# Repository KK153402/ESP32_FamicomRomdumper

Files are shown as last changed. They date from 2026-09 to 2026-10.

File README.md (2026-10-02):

# Famicom ROM Dumper

ESP32と汎用ロジックICで作る、ファミコン（Family Computer）カセットのROM吸い出し機です。
吸い出したデータはiNES形式（`.nes`）で保存され、エミュレータ（Mesen等）でそのまま起動できます。

A Famicom cartridge ROM dumper built with an ESP32 and standard 74-series logic.
Dumps are saved in iNES format (`.nes`) and boot directly in emulators such as Mesen.

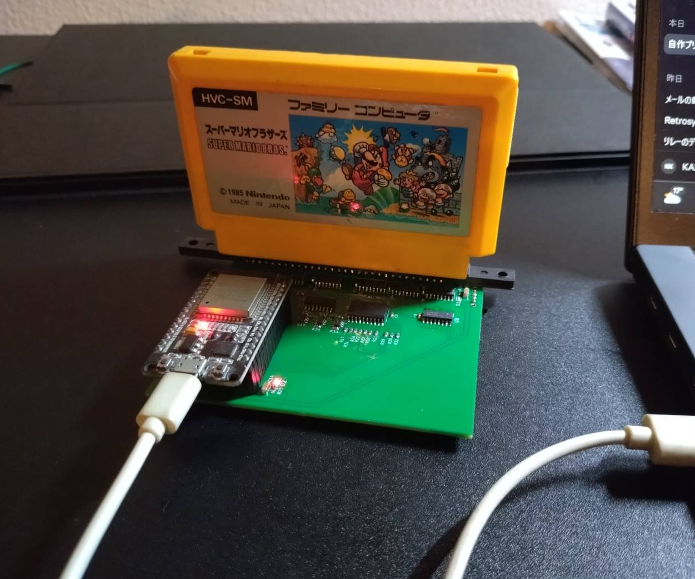
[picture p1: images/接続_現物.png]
基板の外観

<!-- 基板写真 / board photo -->
<!-- ![board](docs/images/board.jpg) -->

---

## 特徴 / Features

- **ESP32 + シフトレジスタ構成**：74HCT595 ×6 / 74HCT165 ×2 でカセットバス54本をGPIO 16本に圧縮
- **5V系ロジックを直接駆動**：シフトレジスタを5Vで動かし、TTLしきい値（HCT/AHCT）で3.3V信号を受ける。大量のレベル変換ICが不要
- **カセット保護**：カセット電源（`VCC_CART`）の独立遮断と、バス全体のHi-Z化（`BUS_EN_N`）
- **ダンプの信頼性**：2回読み出して一致を確認し、CRC32で転送エラーも検出
- **自動判定**：PRG容量（16 KB / 32 KB）とミラーリング（垂直 / 水平）

- **ESP32 + shift registers**: 54 cartridge bus signals driven from 16 GPIOs using 6× 74HCT595 and 2× 74HCT165
- **Direct 5 V logic drive**: shift registers run at 5 V with TTL input thresholds (HCT/AHCT), accepting 3.3 V signals without bulk level shifters
- **Cartridge protection**: switchable cartridge power rail (`VCC_CART`) and bus tri-state control (`BUS_EN_N`)
- **Verified dumps**: every cartridge is read twice and compared; CRC32 checks the serial transfer
- **Auto detection**: PRG size (16 KB / 32 KB) and nametable mirroring (vertical / horizontal)

## 対応カセット / Supported Cartridges

| 状態 | マッパー | 例 |
|---|---|---|
| ✅ 対応 | Mapper 0（NROM-128 / NROM-256） | スーパーマリオブラザーズ、ドンキーコング、バルーンファイト 等 |
| 🚧 未対応 | バンク切替のあるマッパー（UNROM、MMC1、MMC3 など） | 今後対応予定 |

| Status | Mapper | Examples |
|---|---|---|
| ✅ Supported | Mapper 0 (NROM-128 / NROM-256) | Super Mario Bros., Donkey Kong, Balloon Fight, etc. |
| 🚧 Not yet | Bank-switching mappers (UNROM, MMC1, MMC3, ...) | Planned |

60ピンのファミコン用カセット専用です。72ピンの海外版NESカセットは物理的に挿さりません。
For 60-pin Famicom cartridges only. 72-pin NES cartridges do not fit.

## 動作確認済み / Tested

| タイトル | 構成 | 結果 |
|---|---|---|
| スーパーマリオブラザーズ | NROM-256（PRG 32 KB + CHR 8 KB）、垂直ミラー | ✅ Mesenで起動・プレイ確認 |

## リポジトリ構成 / Repository Layout

```
famicom-rom-dumper/
├── README.md
├── LICENSE
├── hardware/           Kicadの回路図,ガーバーデータ
│   └── ERRATA.md       rev1の既知の問題 / Known issues in rev1
├── firmware/           ESP32ファーム（PlatformIO） / ESP32 firmware
├── tools/              PC側ダンプスクリプト / Host-side dump script
└── docs/
    ├── hardware.md     部品表・全接続・電源設計 / BOM, netlist, power design
    ├── bringup.md      組み立て後〜Mesen起動までの手順 / Bring-up to first boot
    ├── protocol.md     シリアルコマンド仕様 / Serial protocol
    └── design-notes.md 設計判断と技術解説 / Design rationale and technical notes
```

## クイックスタート / Quick Start

詳細は [docs/bringup.md](docs/bringup.md) を参照してください。
See [docs/bringup.md](docs/bringup.md) for the full procedure.

1. `firmware/` をPlatformIOでESP32に書き込む / Flash `firmware/` to the ESP32 with PlatformIO
2. カセットを挿してカセット電源スイッチ（SW1）をON / Insert a cartridge and turn SW1 (cartridge power) on
3. PCでダンプ / Dump from the PC:

```
pip install pyserial
python tools/dump_nes.py COM5 game.nes
```

4. SW1をOFFにしてからカセットを抜く / Turn SW1 off before removing the cartridge

```
BUS_EN_N = 0 (enabled)
pass 1: PRG 32KB  CHR 8KB  mirror=V  CRC32=D445F698  (11.5s)
pass 2: CRC32=D445F698
BUS_EN_N = 1 (Hi-Z)
OK: game.nes (40976 bytes)  PRG+CHR CRC32=D445F698
```

## ハードウェア概要 / Hardware Overview

| 部品 / Part | 型番 / Part number | 数 / Qty | 役割 / Role |
|---|---|---|---|
| MCU | ESP32-WROOM-32E DevKit（30ピン） | 1 | 制御・USBシリアル / Control, USB serial<br>[購入先 / Source (AliExpress)](https://ja.aliexpress.com/item/1005008771142129.html) |
| シフトレジスタ（出力） | SN74AHCT595D | 6 | アドレス29本 + データ書き込み16本 / Address and data out |
| シフトレジスタ（入力） | CD74HCT165M | 2 | データ読み出し16本 / Data in |
| バッファ | SN74AHCT244 | 1 | 制御線6本 3.3 V → 5 V / Control lines |
| レベル変換 | SN74LVC1T45 | 3 | 5 V → 3.3 V（MISO、CIRAM 2本） |
| コネクタ | ファミコン60ピン 2.54 mmピッチ | 1 | カセットスロット / Cartridge slot<br>[購入先 / Source (AliExpress)](https://ja.aliexpress.com/item/1005006124592648.html) |

全部品表と接続は [docs/hardware.md](docs/hardware.md) にあります。
The full BOM and netlist are in [docs/hardware.md](docs/hardware.md).

## 注意 / Legal Notice

- **吸い出したROMイメージを配布しないでください。** このツールは、自分が所有するカセットのバックアップや研究目的の私的使用を想定しています。このリポジトリにROMイメージは含まれていません
- **Do not distribute ROM images.** This tool is intended for personal backup and research using cartridges you own. No ROM images are included in this repository.

- カセットの抜き差しは必ずカセット電源（SW1）をOFFにしてから行ってください。通電中の抜き差しはカセットと基板を破損するおそれがあります
- Always turn off cartridge power (SW1) before inserting or removing a cartridge. Hot-swapping can damage both the cartridge and the board.

## 参考資料 / References

- [NESdev Wiki](https://www.nesdev.org/wiki/) — Cartridge connector, iNES format, mapper documentation
- [MesenCE](https://github.com/nesdev-org/MesenCE) — エミュレータ / emulator used for verification

## ライセンス / License

MIT License. ハードウェア（KiCadデータ）・ファームウェア・ツールのすべてに適用します。
MIT License, applied to the hardware design files, firmware, and tools.

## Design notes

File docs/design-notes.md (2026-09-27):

# 設計ノート / Design Notes

このROMダンパーの設計判断の理由と、技術的な背景をまとめた文書です。部品表と接続は [hardware.md](hardware.md)、手順は [bringup.md](bringup.md) を参照してください。

---

## 1. 全体方針

### 1.1 なぜFPGAではなくESP32なのか

ファミコンのカセットに載っているマスクROMは**完全スタティック**です。アドレスを与えて出力を有効にすれば、何秒待っても同じデータを出し続けます。ファミコン本体はCPUサイクル559 ns、PPU読み出しの窓は約372 nsで動いていますが、これは本体側の都合であって、ROMを読むだけならクロックに合わせる必要はありません。

したがって、ダンパーには速度要件がありません。1 kHzで読んでも正しく読めます。この性質を使うと、以下の設計が可能になります。

- 54本のバス信号をシフトレジスタで圧縮し、MCUのGPIO数の制約を回避する
- 汎用MCU（ESP32）とUSBシリアルだけでPCへ転送する

リアルタイムでカセットを駆動する必要がある場合（カセットを挿してそのままゲームを動かす機械）は、PPUの372 nsの窓に間に合わせるためFPGAが必要になります。このダンパーは、その前段階として「カセットのバスを正しく扱えること」を確認する位置づけでもあります。

### 1.2 カセットバスの概要

60ピンのファミコンカセットは、2つの独立したバスを持っています。

| バス | 信号 | 本数 | 内容 |
|---|---|---|---|
| CPUバス | A0〜A14、D0〜D7、M2、/ROMSEL、R/W、/IRQ | 27 | PRG-ROM（プログラム）へのアクセス |
| PPUバス | PA0〜PA13、PD0〜PD7、/RD、/WR、/A13、CIRAM A10、CIRAM /CE | 27 | CHR-ROM（画像データ）へのアクセス、画面用RAMの制御 |

ポイントは以下の3つです。

- **CPUバスにA15は出ていません。** 代わりに `/ROMSEL` = NOT(A15 AND M2) が出ています。`$8000`〜`$FFFF` を読むには、A0〜A14を出してM2 = H、/ROMSEL = L にします
- **CIRAM A10 はカセットからの出力です。** 本体の画面用RAM（2 KB）のアドレスA10をカセットが決めることで、ミラーリング（画面の繋がり方）をカセット側が選べる仕組みです
- ピン間隔は **2.54 mm（0.1インチ）** です。海外版NES（72ピン）の2.50 mmとは異なり、汎用のカードエッジコネクタと同じピッチです

---

## 2. ピン数の圧縮

### 2.1 構成

| 用途 | 本数 | 方式 | ESP32側のピン数 |
|---|---|---|---|
| アドレス（CPU 15 + PPU 14） | 29 | 74AHCT595 × 4 のデイジーチェーン | 共通 |
| データ書き込み（CPU 8 + PPU 8） | 16 | 74AHCT595 × 2 のデイジーチェーン | 共通 |
| データ読み出し（CPU 8 + PPU 8） | 16 | 74HCT165 × 2 のデイジーチェーン | 共通 |
| シフトレジスタの共通線 | — | SCK、MOSI、MISO、RCLK × 2、/OE × 2、/PL | 8 |
| 制御線 | 6 | 74AHCT244 経由で直接 | 6 |
| CIRAM | 2 | 74LVC1T45 経由で直接 | 2 |
| **合計** | **54 + 保護** | | **16** |

アドレス系とデータ系の595は、SCK（シフトクロック）とMOSI（シリアルデータ）を共有しています。出力を更新するタイミング（RCLK）だけを分けているので、片方に送ったデータがもう片方の出力に現れることはありません。

### 2.2 デイジーチェーンのバイト順

595はチェーンの先頭から順にデータが押し出されるため、**最初に送ったバイトがチェーンの末尾のICに到着します**。MSBファーストで送ると、bit7がQH、bit0がQAに対応します。

アドレス系のチェーンは MOSI → U1 → U2 → U3 → U4 なので、送る順番は逆になります。

| 送信順 | 到着するIC | 内容 |
|---|---|---|
| 1バイト目 | U4 | `{00, PA13..PA8}` |
| 2バイト目 | U3 | `{PA7..PA0}` |
| 3バイト目 | U2 | `{0, A14..A8}` |
| 4バイト目 | U1 | `{A7..A0}` |

165は逆方向で、U8 → U7 → MISO の順にチェーンされているので、最初に受け取るバイトがU7（CPUデータ）、次がU8（PPUデータ）です。

### 2.3 165のパラレル入力の割り当て

165は **A → B → C → … → H → QH** の方向にシフトします。つまり、ロード直後にQHに出ているのは**Hピンの値**で、最初に受信されます。MSBファーストで受信するとき最初のビットがbit7なので、**Hピン（6番）にD7、Aピン（11番）にD0**を接続します。

165のピン番号はA〜Dが11〜14、E〜Hが3〜6と飛んでいるため、回路図で取り違えやすい箇所です。実際に設計段階で、ピン11〜14を逆順に接続するミスが2回発生しました。この場合、上位4ビットは正常なまま下位4ビットだけが反転するので、値をぱっと見ても気づきにくい壊れ方をします。

---

## 3. レベル変換の考え方

ESP32は3.3 V、カセットのROMとマッパーは5 Vで動作します。54本すべてにレベル変換ICを入れると部品が増えるため、ロジックICの入力しきい値を使って大半を省略しています。

### 3.1 シフトレジスタを5Vで動かす

**74HCT / 74AHCT シリーズは、5 V電源で動作しながら入力しきい値がTTLレベル（VIH = 2.0 V）です。** 3.3 Vの信号をそのままHとして受けられ、出力は5 Vで振れます。

| シリーズ | VCC = 5 V時のVIH（Hと判定される最低電圧） | ESP32の出力（VOH ≧ 2.64 V）を受けられるか |
|---|---|---|
| 74HC | 約3.5 V（0.7 × VCC） | ✗ |
| 74AHC | 約3.5 V（0.7 × VCC） | ✗ |
| 74HCT | 2.0 V | ✅ 余裕0.64 V以上 |
| 74AHCT | 2.0 V | ✅ 同上 |

ESP32のVOHはデータシート上 0.8 × VDD = 2.64 V（最小値）です。実際の出力はほぼ3.3 Vなので、HCT/AHCTのVIH 2.0 Vに対して十分な余裕があります。

**型番末尾の「T」が決定的に重要です。** 74HC595や74AHC595を使うと、3.3 Vの入力がHと判定されず、回路が成立しません。

入手性の都合で、595はHCTではなくAHCT（SN74AHCT595D）を使っています。AHCTはHCTと同じTTLしきい値を持ち、伝搬遅延はHCTより短く（数ns〜十数ns）、ピン配置も同一なので、置き換えて問題ありません。一方でAHCTは立ち上がりが速い分、多数の出力が同時に切り替わるときの電源の揺れが大きいので、各ICのパスコン（0.1 µF）を最短で配置し、10 µFのバルクコンデンサも置いています。

なお、AHCTファミリには165がないため、読み出し側はHCT（CD74HCT165）です。HCTとAHCTは同じ電源・同じしきい値なので混在して問題ありません。

### 3.2 制御線を74AHCT244で受け直す理由

595の出力は5 V CMOSレベルで振れるので、カセットへそのまま出せます。一方、ESP32から直接出す制御線（M2、/ROMSEL、R/W、/RD、/WR、/A13）は3.3 Vです。カセット上のマッパーICや5 V CMOSロジックの入力しきい値はVCC = 5 Vで約3.5 Vなので、3.3 Vでは確実にHと判定されません。

そこで、この6本だけを74AHCT244（TTLしきい値入力、5 V出力）で受け直しています。

### 3.3 5 V → 3.3 V方向

ESP32の入力は5 Vトレラントではありません。カセットからESP32に向かう信号は以下の3本だけで、それぞれ74LVC1T45（VCCA = 3.3 V、VCCB = 5 V、DIR = GND でB→A固定）で降圧しています。

- 165のシリアル出力（QH）→ MISO
- CIRAM A10 → GPIO34
- CIRAM /CE → GPIO35

いずれも速度要件が低いので、抵抗分圧でも代替できます。3.3 kΩ + 6.8 kΩの場合、5 V × 6.8 / (3.3 + 6.8) = 3.37 V で、ESP32のVIH（0.75 × VDD = 2.48 V）を満たします。

---

## 4. バスの保護設計

### 4.1 CPUデータバスとPPUデータバスの分離

データ書き込み用の595は、CPU側（U5）とPPU側（U6）に分けています。1個の595の出力をCPU D0〜D7とPPU D0〜D7の両方に接続すると、2本の独立したバスが恒久的に短絡します。ダンプ動作だけなら書き込みを使わないので問題が表面化しにくいですが、カセット側がデータバスを駆動したときにバス競合が起きます。

### 4.2 カセット電源の独立（`VCC_CART`）

カセットの抜き差しのため、スイッチ（SW1）でカセットの電源を切れるようにしています。このとき**遮断するのはカセットの電源だけ**で、基板上のロジックICは常時給電のままにします。

基板全体の5 Vを切ると、ESP32（USBから給電され動き続ける）が電源の落ちたICの入力に3.3 Vを加える状態になります。入力保護ダイオード経由でICの電源ラインに電流が流れ込み、ICが中途半端に動作したり、ラッチアップの原因になります。

### 4.3 バスのHi-Z化（`BUS_EN_N`）

カセットの電源だけを切っても、595と244は5 Vを出力し続けます。今度は電源の落ちたカセットのICに、アドレス線経由で電流が流れ込みます。

これを防ぐため、アドレス出力（U1〜U4）と制御線（U9）の出力イネーブル（/OE）をまとめて1本のGPIO（`BUS_EN_N`）で制御しています。

```
カセットを抜く：  BUS_EN_N = H（Hi-Z） → SW1 OFF → 抜く
カセットを挿す：  挿す → SW1 ON → BUS_EN_N = L（有効）
```

`BUS_EN_N` は10 kΩで3.3 Vにプルアップしているので、ESP32の起動中やリセット中は自動的にHi-Zになります。74AHCTの/OE入力もTTLしきい値なので、3.3 VでHと判定されます。

### 4.4 プル抵抗の配置

Hi-Zにした線や、ESP32のリセット中にGPIOが浮いた線の電圧を確定させるため、プル抵抗を両側に置いています。

| 位置 | プル先 | 目的 |
|---|---|---|
| 244の入力側（3.3 V側）6本 | +3.3 V（M2のみGND） | ESP32のリセット中、244の入力が浮いてカセットへ不定な信号が出ないようにする |
| 244の出力側（5 V側）6本 | `VCC_CART`（M2のみGND） | `BUS_EN_N` でHi-Zにしたとき、カセット側の制御線を非アクティブに保つ |
| データバス16本 | `VCC_CART` | 何も駆動していないバスを `$FF` として読む（オープンバスの検出） |
| CIRAM 2本 | `VCC_CART` | カセット未挿入時に74LVC1T45の入力が浮かないようにする |

**カセット側のプル抵抗は `+5V` ではなく `VCC_CART` に接続しています。** `+5V` に接続すると、SW1を切っても各抵抗からカセットの入力保護ダイオード経由で電流が流れ込みます。

(5 V − 0.6 V) ÷ 10 kΩ ≒ 0.44 mA/本、21本で最大約9 mA

この電流でカセットの電源ラインが弱く持ち上がり、電源を切ったつもりでもカセットが中途半端に通電した状態になります。`VCC_CART` に接続すれば、カセット通電中の動作はまったく同じで、電源を切ればプル抵抗も一緒に落ちます。

**244の出力側のプル先を3.3 Vにしてはいけません。** Hi-Z時にカセット側の線が3.3 Vになり、5 V CMOSのVIH（約3.5 V）を満たさない不定領域に入るためです。

**74LVC1T45の入力を浮かせてはいけません。** CMOS入力が中間電位に浮くと入力段に貫通電流が流れ、消費電流の増加や発振の原因になります。CIRAMの2本は、カセット未挿入時に接続先がコネクタのパッドだけになるため、プルアップが必要です。

---

## 5. 読み出しシーケンス

### 5.1 PRG-ROM（CPUバス）

```
1. 595でアドレス A0〜A14 を出力（RCLK_ADDRで確定）
2. R/W = H、M2 = H、/ROMSEL = L     ← $8000〜$FFFF が選択される
3. 2 µs 待つ
4. /PL をパルス → 165にデータバスをロード
5. 165を16ビット読み、先頭8ビットをCPUデータとする
6. /ROMSEL = H、M2 = L
```

当時のマスクROMのアクセスタイムは150〜250 ns程度なので、2 µsの待ち時間は8倍以上の余裕があります。

### 5.2 CHR-ROM（PPUバス）

```
1. 595でアドレス PA0〜PA12 を出力（PA13 = 0）
2. /A13 = H、/RD = L
3. 2 µs 待つ
4. /PL をパルス → 165にロード
5. 165を16ビット読み、後半8ビットをPPUデータとする
6. /RD = H
```

### 5.3 ミラーリングの判定

NROMカセットでは、CIRAM A10がカセット基板上でPPU A10かA11に直結されています。PPUアドレスを `$2400`（PA10 = 1）と `$2800`（PA11 = 1）にして、CIRAM A10がどちらに追従するかを見れば判定できます。

| CIRAM A10 が追従 | ミラーリング |
|---|---|
| PA10 | 垂直（左右の画面がつながる。横スクロールのゲーム） |
| PA11 | 水平（上下の画面がつながる） |

### 5.4 PRG容量の判定

NROM-128（PRG 16 KB）のカセットはA14を使わないため、`$8000`〜`$BFFF` と `$C000`〜`$FFFF` に同じ内容が見えます。両者を比較して一致すれば16 KB品と判定します。

---

## 6. 74HC165の読み出しとビットバング

### 6.1 起きた問題

最初のファームは、ESP32のハードウェアSPI（MODE0、1 MHz）で165を読んでいました。カセット未挿入でデータバスがすべてH（プルアップ）の状態なのに、以下の値が返りました。

```
CPU D=FF  PPU D=FE       ← 期待値は FF FF
```

### 6.2 原因の特定

この回路で「0」が出てくる場所は1つしかありません。**チェーン末尾のU8のシリアル入力（SER）がGNDに接続されている**ことです。165はクロックを1回余分に進めると、末尾にSERの値が入ってきます。

```
正しい読み：  [U7: H G F E D C B A] [U8: H G F E D C B A]    → FF FF
1ビットずれ：  [U7: G F E D C B A][U8: H] [U8: G F E D C B A][SER=0]  → FF FE
```

つまり、**先頭ビット（U7のH = CPU D7）を読む前にシフトが1回起きて、そのビットを失っていた**ことになります。データがすべて1なので、ずれの影響が末尾の0としてだけ見えていました。

### 6.3 仕組み

165は、/PLでロードした直後から最初のビット（H）をQHに出していて、CPの**立ち上がり**でシフトします。SPI MODE0は、同じ**立ち上がり**でMISOを取り込みます。

165のシフト（CP → QH の伝搬遅延）と、ESP32がMISOを取り込むタイミングが同じクロックエッジで競合します。観測結果から、ESP32はシフト後の値を取り込んでいたと判断できます。

### 6.4 対策

SPI MODE2（クロックの待機レベルがH、立ち下がりで取り込み）に変えれば165の読み出しは正しくなりますが、今度は595への書き込み側で、MOSIの変化と595の取り込み（立ち上がり）が同じエッジで競合します。読み出しと書き込みでSPIモードを切り替える方法もありますが、モード切替時にクロックの待機レベルが変わること自体がエッジになり、別の問題を起こします。

そこで、**ハードウェアSPIをやめて、GPIOでクロックを1ビットずつ操作する（ビットバング）方式**に変更しました。

```cpp
uint8_t shiftInByte() {
  uint8_t v = 0;
  for (int i = 0; i < 8; i++) {
    v = (v << 1) | digitalRead(PIN_MISO);   // 先に読む
    sclk();                                 // それからシフト
  }
  return v;
}
```

「QHを読んでからクロックを上げる」順番がコードで固定されるので、タイミング競合が原理的に起きません。

### 6.5 速度

| 処理 | 計算 | 時間 |
|---|---|---|
| シフトクロック1回 | 半周期1 µs × 2 + GPIO操作 | 約2.3 µs |
| 1バイト読み出し | アドレス32クロック + 読み出し16クロック + 待ち約5 µs | 約110 µs |
| 40 KB 読み出し | 110 µs × 40960 | 約4.5 秒 |
| 40 KB 転送 | 115200 bps ÷ 10 bit = 11.52 KB/s | 約3.6 秒 |

実測では1回あたり11.5秒（読み出し、転送、判定処理を含む）でした。ダンパーとしては十分な速度です。

---

## 7. ダンプの信頼性

カセットの端子は30年以上前のもので、接点不良が起きやすい部品です。接点不良は「毎回同じ値が化ける」のではなく「たまに化ける」形で現れるため、1回読んだだけでは気づけません。

PC側スクリプトは以下の2段階で確認しています。

1. **転送の確認**：ESP32側とPC側で CRC-32 を計算して照合（USBシリアル転送の化けを検出）
2. **読み出しの確認**：カセットを2回ダンプして、PRG・CHR・ミラーリングがすべて一致した場合のみ保存（接点不良による化けを検出）

---

## 8. 回路図レビューで見つかった設計ミス

基板発注前のネットリストのレビューで、以下のミスが見つかり修正しました。**いずれもKiCadのERC（電気的ルールチェック）では検出できません。** ネットリストを出力して、人の目で確認する必要があります。

| ミス | 放置した場合の結果 | 教訓 |
|---|---|---|
| 244の入力側と出力側が同じネット名で短絡 | ESP32のGPIOがカセットの5 Vラインに直結されて壊れる | バッファの入出力は必ず別名（`M2_3.3V` / `M2_5V`）にする |
| 165のピン11〜14が逆順 | 下位4ビットだけが反転する | 165はピン番号とビット順が直感に反する |
| 244の/OE（ピン1）が未接続 | 出力が不定になる | 未接続ピンの一覧（`unconnected-`）を全部読む |
| RCLK_DATAをGPIO3に割り当て | GPIO3はUART0の受信ピンで、書き込みもシリアル通信もできなくなる | ESP32のGPIO1/3は使わない |
| 244出力側のプル先が3.3 V | Hi-Z時にカセット側が不定電位になる | プル先の電圧は、受ける側のしきい値で決める |
| カセット側のプル先が `+5V` | 電源を切ったカセットに電流が流れ込む | 遮断する電源に繋がる信号のプル先も一緒に遮断する |
| CIRAMのレベル変換入力が浮く | カセット未挿入時にLVC入力が浮く | 「片側がコネクタのパッドだけ」の入力ピンを探す |
| ネット名の `/` | KiCadで `{slash}` に化ける | 負論理は `_N` で表す |

---

## 9. 立ち上げで分かったこと

実機での立ち上げ時に、以下のような「故障に見えるが故障ではない」現象がありました。いずれも設計どおりの動作です。

| 現象 | 原因 |
|---|---|
| データ線の電圧が約2.8 V | SW1 OFFでプルアップの電源（`VCC_CART`）がなく、線が浮いていた。浮いたCMOSノードをテスタで測ると意味のない中間電圧が見える |
| 制御線のうちM2だけ5 Vにならない | `E 0` を送っておらず、244がHi-Zだった。M2以外の5本は出力側プルアップで5 Vに見えていた（M2だけプルダウン） |

後者は、**`E 0` を送らないまま「5 Vが出た」ことだけを確認すると、ほかの5本も正常に見えてしまう**という点で注意が必要です。制御線の確認では、0 Vに落ちることを必ず確認します。

また、ジャンパー線がなくても回路の正しさを確認できる「既知の値」がいくつもありました。

| 既知の値 | 確認できること |
|---|---|
| U8のSERがGND | 165の読み出しのビットずれ |
| 割り込みベクタが `$8000` 以上 | CPUアドレス線・データ線・制御線 |
| ほとんどのソフトの先頭命令が `78 D8`（SEI、CLD） | データ線のビット順 |
| NROMのCIRAM A10はPA10かPA11に直結 | PPUアドレス線とCIRAM経路 |

---

## 10. 今後の拡張

| 項目 | 内容 |
|---|---|
| UNROM対応 | `$8000`〜`$FFFF` への書き込みでバンク切替。ROMとの**バス競合**があるため、書き込む値がROM上のその番地の値と一致している必要がある |
| MMC1対応 | 5回のシリアル書き込みでレジスタを設定。連続するCPUサイクルの書き込みは無視されるため、書き込みの間にM2を1サイクル以上入れる |
| MMC3対応 | `$8000`/`$8001` でバンク選択と値を設定 |
| CHR-RAM判定 | CHR領域に書き込んで読み戻せればRAM（iNESヘッダのCHRサイズを0にする） |
| バッテリーバックアップSRAM | `$6000`〜`$7FFF`。/ROMSEL = H の領域で、M2で有効になる |
| マッパー自動判定 | 吸い出したデータのCRCを既知のデータベースと照合する |
| 高速化 | シリアルのボーレートを上げる（ESP32のUSBシリアル変換ICの上限まで） |

---

## 参考資料

- NESdev Wiki — [Cartridge connector](https://www.nesdev.org/wiki/Cartridge_connector)、[Famicom cartridge dimensions](https://www.nesdev.org/wiki/Famicom_cartridge_dimensions)、[iNES](https://www.nesdev.org/wiki/INES)、[NROM](https://www.nesdev.org/wiki/NROM)
- Texas Instruments — SN74AHCT595、CD74HCT165、SN74AHCT244、SN74LVC1T45 データシート
- Espressif — ESP32 データシート（DC特性：VIH、VOH）

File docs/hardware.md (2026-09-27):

# ハードウェア仕様 / Hardware Specification

ESP32ベースのファミコンROMダンパー（rev1基板）の部品表・全接続・電源設計。**配線に関してはこの文書を正とする。**

- 組み立て後の動作確認〜ダンプ手順 → [bringup.md](bringup.md)
- 設計判断の理由と技術解説 → [design-notes.md](design-notes.md)
- シリアルコマンド仕様 → [protocol.md](protocol.md)
- rev1の既知の問題 → [../hardware/ERRATA.md](../hardware/ERRATA.md)

---

## 0. ネット命名規則

**74HCT244を挟む6本の制御線は、入力側と出力側で必ず別のネット名にすること。** 同名にすると、回路図上で意図せず1本に繋がっても気づけない。

| ESP32側（3.3 V） | U9 経路 | カート側（5 V） | J1 |
|---|---|---|---|
| `M2_3.3V` | 1A1(2) → 1Y1(18) | `M2_5V` | 32 |
| `ROMSEL_N_3.3V` | 1A2(4) → 1Y2(16) | `ROMSEL_N_5V` | 44 |
| `RW_3.3V` | 1A3(6) → 1Y3(14) | `RW_5V` | 14 |
| `PPU_RD_N_3.3V` | 1A4(8) → 1Y4(12) | `PPU_RD_N_5V` | 17 |
| `PPU_WR_N_3.3V` | 2A1(11) → 2Y1(9) | `PPU_WR_N_5V` | 47 |
| `PPU_A13_N_3.3V` | 2A2(13) → 2Y2(7) | `PPU_A13_N_5V` | 49 |

**この12個のネットに同じノードが2つ入ってはいけない。** ERCでは検出できないので、ネットリスト出力後に目視確認すること（§11のチェック方法を参照）。

### KiCadでの注意

- **ネット名に `/` を使わない。** KiCadでは階層パスの区切り文字として解釈され、ネットリスト上で `{slash}` に化ける。負論理は `_N` サフィックスで表現する（`/ROMSEL` ではなく `ROMSEL_N_5V`）
- 電源レールは `+5V` `+3.3V` `VCC_CART` の3つ。**`VCC_CART` を `+5V` と同名にしない**

---

## 1. 実装方式の選択

| | ユニバーサル基板 | 自作PCB |
|---|---|---|
| パッケージ | DIP | SOP / TSSOP |
| 配線本数 | 手配線で約110本 | 不要 |
| 配線ミスのリスク | 高い | 低い |
| 費用 | 千円程度 | JLCPCB 5枚で$5前後＋送料 |

**推奨：自作PCB。** ネット数が110本近くあり、手配線では配線ミスの切り分けだけで数日溶ける。

---

## 2. 部品表（発注用）

### 2.1 必須部品

| # | 部品 | 型番（SOP/SMD） | 型番（DIP） | 数量 | 発注推奨数 | 備考 |
|---|---|---|---|---|---|---|
| 1 | 60ピン カートリッジスロット | — | — | 1 | 2 | §3参照。**最も納期が長い** |
| 2 | 8bitシフトレジスタ（出力） | **SN74AHCT595D**（SOIC-16） | SN74HCT595N | 6 | 8 | **AHCではなくAHCT。§2.3参照** |
| 3 | 8bitシフトレジスタ（入力） | CD74HCT165M（SOIC-16） | CD74HCT165E | 2 | 4 | AHCTファミリに `'165` は存在しない。§2.5に代替案 |
| 4 | オクタルバッファ | SN74AHCT244D / SN74HCT244DW | SN74HCT244N | 1 | 2 | AHCT / HCT どちらでも可 |
| 5 | 1bitレベル変換 | SN74LVC1T45DBVR（SOT-23-6） | — | 3 | 10 | 5→3.3 V。§2.4に代替案 |
| 6 | ESP32モジュール | ESP32-WROOM-32E | — | 1 | 1 | **WROVER系は不可**（GPIO16/17がPSRAM占有） |
| 7 | 抵抗 10 kΩ | 1608（0603） | 同左 | 32 | 100（1袋） | 内訳は§6 |
| 8 | 抵抗 1 kΩ | 1608 | 同左 | 2 | 20 | LED電流制限 |
| 9 | セラコン 0.1 µF | 1608 | 同左 | 12 | 30 | IC各1個 |
| 10 | 電解 / 積セラ 10 µF | — | — | 3 | 10 | **バルク。+5V入口 / +3.3V入口 / VCC_CART出口** |
| 11 | スライドスイッチ | SK-12D11VG3 等 SPDT | 同左 | 1 | 2 | `VCC_CART` の開閉 |
| 12 | LED | 汎用 | 同左 | 2 | 5 | 電源表示 |

### 2.2 任意部品

| # | 部品 | 型番 | 数量 | 備考 |
|---|---|---|---|---|
| 13 | ロードスイッチ | TPS22918DBVR（SOT-23-6） | 1 | SW1をGPIO制御に置き換える場合。**ピン配置はデータシートで確認** |
| 14 | セラコン 1 nF | 1608 | 1 | TPS22918 CTピン |
| 15 | タクトスイッチ | 汎用 | 2 | リセット / ダンプ開始 |
| 16 | 集合抵抗 10 kΩ×8 バス型 | 9ピンSIP等 | 2 | データバス16本のプルアップをまとめる場合 |
| 17 | テストポイント | — | 10〜 | 未使用GPIOに配置しておくとデバッグが楽 |

### 2.3 発注時の最重要注意：入力しきい値に「T」が必要

**74HC595 や 74AHC595 を買うと動きません。** 必ず末尾に **T** の付く **HCT / AHCT** を発注すること。

| シリーズ | VCC = 5 V時の VIH | ESP32の3.3V出力 |
|---|---|---|
| 74HC | 3.5 V | **認識されない（設計不成立）** |
| 74AHC | 3.85 V | **認識されない（設計不成立）** |
| 74HCT | 2.0 V | 確実に認識される |
| 74AHCT | 2.0 V | 確実に認識される |

**DigiKeyの検索結果では `SN74AHCT595D` と `SN74AHC595D` が隣接表示される。** カートに入れる際、型番の「T」を目視確認すること。

### 2.3.1 HCT595 → AHCT595 への変更について

SN74HCT595Dが在庫切れのため **SN74AHCT595D** を採用。この設計がHCTに要求しているのは入力しきい値のみで、AHCTも同じTTLレベル入力（VIH = 2.0 V）を持つため前提条件は維持される。

| | 74HCT595 | 74AHCT595 |
|---|---|---|
| VIH（VCC = 5 V） | 2.0 V | 2.0 V |
| 伝搬遅延 | 20〜30 ns | 5〜9 ns |
| 出力電流 | ±6 mA | ±8 mA |
| ピン配置 | — | **HCT595と完全に同一** |

**AHCT採用に伴う注意**：立ち上がりが1〜2 nsと速く、8出力同時スイッチング時のグランドバウンスがHCTより大きい。0.1 µFのパスコンをVCC–GND間に最短配置し（PCBならIC直下の裏面）、**10 µFのバルクコンデンサを必ず入れること**。

**HCTとAHCTの混在は問題ない。** どちらも5V電源・TTLしきい値であり、U1–U6（AHCT595）とU7–U8（HCT165）の混在で不整合は生じない。

### 2.4 74LVC1T45 の代替（SOT-23-6を避けたい場合）

| 用途 | 速度要求 | 代替手段 |
|---|---|---|
| U10：165のQH → MISO | シフトクロック 〜250 kHz | 抵抗分圧（3.3 kΩ + 6.8 kΩ）で可。時定数約45 ns |
| U11：CIRAM A10 → GPIO34 | 静的読み出し | 抵抗分圧で十分 |
| U12：CIRAM /CE → GPIO35 | 静的読み出し | 抵抗分圧で十分 |

分圧比は 5 V × 6.8/(3.3+6.8) = 3.37 V で、ESP32のVIH（2.48 V）を満たす。PCBを起こすなら1T45を推奨。

### 2.5 74HCT165 が入手できない場合

**代替案：SN74LVC165A を VCC = 3.3 V で使う。** LVCは入力が5.5 Vまで許容されるため5Vのデータバスを直接読め、出力も3.3 Vになるので **U10が不要**になる。採用する場合はU7:QHをGPIO19へ直結し、電源を3.3 V系に接続する。

在庫があるならHCT165のままでよい。

---

## 3. 60ピン カートリッジスロットの調達

**代替の効かない部品。最優先で発注すること。**

| 項目 | 値 |
|---|---|
| ピッチ | **2.54 mm（0.1インチ）** |
| 極数 | 30ポジション × 2列 = 60接点 |
| 受け入れ基板厚 | 0.062インチ（1.57〜1.6 mm） |
| 全長 | 約83 mm |

### 調達ルート（推奨順）

**① ファミコン補修用60ピンスロット（推奨）** — eBay / AliExpressで「Famicom 60 pin cartridge slot connector」等。純正カセットの挿入を前提に作られているため寸法・保持力とも確実。1個500〜1,500円。中国発送で2〜4週間かかるため**最優先で発注**し、**2個買う**（予備または工程3用）。

**② 汎用カードエッジコネクタ** — DigiKey / Mouserで Pitch 0.100"、60 positions（30 per row）、Accepts board thickness 0.062" で検索。ただし**カセット外装との干渉**に注意。純正カセットはシェルごと挿すため、コネクタの背が低いと外装が当たって奥まで入らない。

**③ ジャンクのファミクローン機から取り外し** — スルーホール実装なので回収可能。

---

## 4. IC一覧と役割

| 参照 | 型番 | 役割 | VCC |
|---|---|---|---|
| U1 | 74AHCT595 | CPU A7–A0 | +5V |
| U2 | 74AHCT595 | CPU A14–A8 | +5V |
| U3 | 74AHCT595 | PPU A7–A0 | +5V |
| U4 | 74AHCT595 | PPU A13–A8 | +5V |
| U5 | 74AHCT595 | CPU D7–D0（書き込み用） | +5V |
| U6 | 74AHCT595 | PPU D7–D0（書き込み用） | +5V |
| U7 | 74HCT165 | CPU D7–D0（読み出し） | +5V |
| U8 | 74HCT165 | PPU D7–D0（読み出し） | +5V |
| U9 | 74AHCT244 | 制御線6本 3.3→5 V | +5V |
| U10 | 74LVC1T45 | U7のQH 5→3.3 V | A:+3.3V / B:+5V |
| U11 | 74LVC1T45 | CIRAM A10 5→3.3 V | 同上 |
| U12 | 74LVC1T45 | CIRAM /CE 5→3.3 V | 同上 |
| U13 | ESP32-WROOM-32E | 制御 | — |

**U5とU6は必ず分ける。** 1個の595でCPU D0–D7とPPU D0–D7の両方を駆動すると、2本の独立したバスネットが恒久的に短絡する。

### デイジーチェーン構成

```
アドレス系： MOSI → U1:SER(14)
             U1:QH'(9) → U2:SER(14) → U2:QH'(9) → U3:SER(14) → U3:QH'(9) → U4:SER(14)
             U4:QH'(9) は未接続（チェーン終端）
             RCLK は U1–U4 共通（RCLK_ADDR）

データ系：   MOSI → U5:SER(14)
             U5:QH'(9) → U6:SER(14)
             U6:QH'(9) は未接続
             RCLK は U5–U6 共通（RCLK_DATA）

読み出し系： U8:SER(10) = GND
             U8:QH(9) → U7:SER(10)
             U7:QH(9) → U10:B(4) → U10:A(3) → MISO
             /PL は U7–U8 共通（PL_165_N）

SRCLK / CP はすべてのIC（U1–U8）で SCK 共通
```

---

## 5. ESP32ピン割り当て

ストラップピン（GPIO 0 / 2 / 5 / 12 / 15）は使用していない。

| GPIO | 信号名 | 接続先 | 方向 |
|---|---|---|---|
| 18 | `SCK` | U1–U8 の SRCLK(11) / CLK(2) | OUT |
| 23 | `MOSI` | U1:SER(14)、U5:SER(14) | OUT |
| 19 | `MISO` | U10:A(3) | IN |
| 26 | `RCLK_ADDR` | U1–U4 の RCLK(12) | OUT |
| **27** | `RCLK_DATA` | U5–U6 の RCLK(12) | OUT |
| 25 | `OE_DATA_N` | U5–U6 の /OE(13) | OUT |
| 33 | `PL_165_N` | U7–U8 の /PL(1) | OUT |
| 21 | `M2_3.3V` | U9:1A1(2) | OUT |
| 22 | `ROMSEL_N_3.3V` | U9:1A2(4) | OUT |
| 32 | `RW_3.3V` | U9:1A3(6) | OUT |
| 16 | `PPU_RD_N_3.3V` | U9:1A4(8) | OUT |
| 17 | `PPU_WR_N_3.3V` | U9:2A1(11) | OUT |
| 4 | `PPU_A13_N_3.3V` | U9:2A2(13) | OUT |
| 34 | `CIRAM_A10` | U11:A(3) | IN（入力専用ピン） |
| 35 | `CIRAM_CE_N` | U12:A(3) | IN（入力専用ピン） |
| **13** | `BUS_EN_N` | U1–U4 の /OE(13)、U9 の 1/OE(1)・2/OE(19) | OUT |

### 使ってはいけないピン

| GPIO | 理由 |
|---|---|
| **1（U0TXD）／ 3（U0RXD）** | USB-シリアル変換ICと接続されている。**出力として使うと信号が衝突し、書き込みもシリアルモニタも使えなくなる。** ブリングアップはUARTコマンドで進めるため致命的 |
| 0 / 2 / 5 / 12 / 15 | ストラップピン。起動モードに影響する |
| 6–11 | 内蔵SPIフラッシュ |
| 16 / 17 | **WROVER系ではPSRAMが占有。** WROOM-32Eでのみ使用可 |

テストポイントは上記以外の空きピン（GPIO14 / 36 / 39 など）に配置する。

---

## 6. 抵抗の配置

### 6.1 データバスのプルアップ（5 V側）

| 参照 | 値 | 接続 | 目的 |
|---|---|---|---|
| R1–R8 | 10 kΩ | `CPU_D0`–`CPU_D7` ↔ **`VCC_CART`** | オープンバス = `$FF` を明示検出 |
| R9–R16 | 10 kΩ | `PPU_D0`–`PPU_D7` ↔ **`VCC_CART`** | 同上 |

**吊り先は `+5V` ではなく `VCC_CART`。** `+5V` に吊ると、SW1を切っても16本の10 kΩ経由で無電源のカセットへ電流が流れ込み（1本あたり約0.4 mA）、カート側の保護ダイオード経由でVCCが弱く逆給電される。`VCC_CART` に吊れば、カート通電中の挙動は同一のまま、電源OFF時にプルアップも一緒に落ちる。

### 6.2 244 入力側の整定（3.3 V側）

**ESP32のリセット中はGPIOがHi-Zになるため、244の入力が浮いてバスが不定になる。** これを防ぐ。

| 参照 | 値 | ネット | 接続先 |
|---|---|---|---|
| R17 | 10 kΩ | `M2_3.3V` | **GND**（プルダウン。L = 非アクティブ） |
| R26 | 10 kΩ | `ROMSEL_N_3.3V` | **+3.3V** |
| R27 | 10 kΩ | `RW_3.3V` | **+3.3V**（H = リード） |
| R28 | 10 kΩ | `PPU_RD_N_3.3V` | **+3.3V** |
| R29 | 10 kΩ | `PPU_WR_N_3.3V` | **+3.3V** |
| R30 | 10 kΩ | `PPU_A13_N_3.3V` | **+3.3V** |

### 6.3 244 出力側の整定（5 V側）

**`BUS_EN_N` でU9をHi-Zにしたとき、カート側の制御線が浮くのを防ぐ。**

| 参照 | 値 | ネット | 接続先 |
|---|---|---|---|
| R32 | 10 kΩ | `M2_5V` | **GND**（プルダウン） |
| R18 | 10 kΩ | `ROMSEL_N_5V` | **`VCC_CART`** |
| R19 | 10 kΩ | `RW_5V` | **`VCC_CART`** |
| R20 | 10 kΩ | `PPU_RD_N_5V` | **`VCC_CART`** |
| R21 | 10 kΩ | `PPU_WR_N_5V` | **`VCC_CART`** |
| R22 | 10 kΩ | `PPU_A13_N_5V` | **`VCC_CART`** |

**3.3 Vに吊ってはいけない。** Hi-Z時にカート側CMOSのVIH（VCC = 5 V時に3.5 V）を満たさず不定領域に入るため、Hi-Z時の保護という設置目的そのものが機能しなくなる。

**`+5V` ではなく `VCC_CART` に吊る。** 理由は§6.1と同じ。

### 6.3.1 CIRAM 2本のプルアップ

| 参照 | 値 | ネット | 接続先 |
|---|---|---|---|
| R33 | 10 kΩ | `CIRAM_A10_5V` | **`VCC_CART`** |
| R34 | 10 kΩ | `CIRAM_CE_N_5V` | **`VCC_CART`** |

**U11:B(4) と U12:B(4) は入力ピンであり、カート未挿入時に浮く。** 74LVC1T45の入力を浮かせると入力段がリニア領域に入り、消費電流の増加と発振の原因になる。またカート未挿入で立ち上げ確認をする際、GPIO34/35がノイズを拾って不定になる。

カセットを挿して通電している間はカート側が両信号を駆動するため、10 kΩが挙動に影響することはない。

### 6.4 その他

| 参照 | 値 | ネット | 接続先 | 目的 |
|---|---|---|---|---|
| R23 | 10 kΩ | `OE_DATA_N` | **+3.3V** | リセット中のHi-Z保証。**5Vに吊らない**（ESP32は5Vトレラントでない） |
| R31 | 10 kΩ | `BUS_EN_N` | **+3.3V** | リセット中はバスHi-Z |
| R24, R25 | 1 kΩ | LED | — | 電流制限 |

**R23 / R31 は3.3 Vプルアップで問題ない。** 接続先のU1–U6・U9の/OEはAHCT入力（VIH = 2.0 V）なので、3.3 VでHとして確実に認識される。

**10 kΩの合計：16 + 6 + 6 + 2 + 2 = 32本**

---

## 7. 60ピン 全ネット表

```
[表面 01-30]                                    [裏面 31-60]
01 GND           = GND                          31 CartridgePresent = NC ※注記
02 CPU_A11       = U2:QD(3)                     32 M2_5V            = U9:1Y1(18), R32
03 CPU_A10       = U2:QC(2)                     33 CPU_A12          = U2:QE(4)
04 CPU_A9        = U2:QB(1)                     34 CPU_A13          = U2:QF(5)
05 CPU_A8        = U2:QA(15)                    35 CPU_A14          = U2:QG(6)
06 CPU_A7        = U1:QH(7)                     36 CPU_D7  = U5:QH(7),  U7:H(6),  R1
07 CPU_A6        = U1:QG(6)                     37 CPU_D6  = U5:QG(6),  U7:G(5),  R2
08 CPU_A5        = U1:QF(5)                     38 CPU_D5  = U5:QF(5),  U7:F(4),  R3
09 CPU_A4        = U1:QE(4)                     39 CPU_D4  = U5:QE(4),  U7:E(3),  R4
10 CPU_A3        = U1:QD(3)                     40 CPU_D3  = U5:QD(3),  U7:D(14), R5
11 CPU_A2        = U1:QC(2)                     41 CPU_D2  = U5:QC(2),  U7:C(13), R6
12 CPU_A1        = U1:QB(1)                     42 CPU_D1  = U5:QB(1),  U7:B(12), R7
13 CPU_A0        = U1:QA(15)                    43 CPU_D0  = U5:QA(15), U7:A(11), R8
14 RW_5V         = U9:1Y3(14), R19              44 ROMSEL_N_5V      = U9:1Y2(16), R18
15 IRQ_N         = NC（工程1未使用）             45 Audio_from_2A03  = NC
16 GND           = GND                          46 Audio_to_RF      = NC
17 PPU_RD_N_5V   = U9:1Y4(12), R20              47 PPU_WR_N_5V      = U9:2Y1(9), R21
18 CIRAM_A10_5V  = U11:B(4), R33                49 CIRAM_CE_N_5V    = U12:B(4), R34
19 PPU_A6        = U3:QG(6)                     49 PPU_A13_N_5V     = U9:2Y2(7), R22
20 PPU_A5        = U3:QF(5)                     50 PPU_A7           = U3:QH(7)
21 PPU_A4        = U3:QE(4)                     51 PPU_A8           = U4:QA(15)
22 PPU_A3        = U3:QD(3)                     52 PPU_A9           = U4:QB(1)
23 PPU_A2        = U3:QC(2)                     53 PPU_A10          = U4:QC(2)
24 PPU_A1        = U3:QB(1)                     54 PPU_A11          = U4:QD(3)
25 PPU_A0        = U3:QA(15)                    55 PPU_A12          = U4:QE(4)
26 PPU_D0 = U6:QA(15), U8:A(11), R9             56 PPU_A13          = U4:QF(5)
27 PPU_D1 = U6:QB(1),  U8:B(12), R10            57 PPU_D7 = U6:QH(7), U8:H(6),  R16
28 PPU_D2 = U6:QC(2),  U8:C(13), R11            58 PPU_D6 = U6:QG(6), U8:G(5),  R15
29 PPU_D3 = U6:QD(3),  U8:D(14), R12            59 PPU_D5 = U6:QF(5), U8:F(4),  R14
30 VCC_CART      = SW1:A(1), C15               60 PPU_D4 = U6:QE(4), U8:E(3),  R13
```

空き出力：U2:QH(7)、U4:QG(6)、U4:QH(7) → 未接続でよい。

**ピン31について**：NESdev Wikiでは「CartridgePresent または +5V供給（カートによる）」とされている。工程1はNCで開始するが、読めないカセットが出た場合に+5Vへ接続して試せるよう、**ソルダージャンパまたは未実装の0Ω抵抗パターンを用意しておく**。

---

## 8. IC共通ピンの処理

### 8.1 74AHCT595（U1–U6）

ピン配置は74HCT595と完全に同一。

| ピン | 名称 | 処理 |
|---|---|---|
| 8 | GND | GND |
| 9 | QH'（シリアル出力） | 次段のSER(14)へ。U4・U6は未接続 |
| 10 | /SRCLR | **+5V**（リセットしない） |
| 11 | SRCLK | `SCK` 共通 |
| 12 | RCLK | U1–U4 = `RCLK_ADDR` / U5–U6 = `RCLK_DATA` |
| 13 | /OE | U1–U4 = **`BUS_EN_N`** / U5–U6 = `OE_DATA_N` |
| 14 | SER | 前段のQH'(9)、または U1・U5 は `MOSI` |
| 16 | VCC | +5V |

出力ビットの対応：**MSBファーストで送ると bit7 → QH、bit0 → QA**。したがってQAが最下位ビット（A0、D0）。

### 8.2 74HCT165（U7–U8）— パラレル入力のマッピングに注意

165は **A → B → C → … → H → QH** の順にシフトするため、**H（ピン6）が最初に出力される**。MSBファーストで受信すると最初のビットがbit7になるので、**Hに D7 を接続する**。

| ピン | 記号 | 出力される順番 | 接続 |
|---|---|---|---|
| 11 | A | 8番目（最後） | **D0** |
| 12 | B | 7番目 | **D1** |
| 13 | C | 6番目 | **D2** |
| 14 | D | 5番目 | **D3** |
| 3 | E | 4番目 | **D4** |
| 4 | F | 3番目 | **D5** |
| 5 | G | 2番目 | **D6** |
| 6 | H | 1番目（最初） | **D7** |

**ピン11–14を逆順（11=D3, 12=D2, 13=D1, 14=D0）に繋ぐと、下位ニブルだけがビット反転する。** 上位ニブルは正常に見えるため気づきにくい。

その他のピン：

| ピン | 名称 | 処理 |
|---|---|---|
| 1 | /PL（SH//LD） | `PL_165_N` 共通 |
| 2 | CP（CLK） | `SCK` 共通 |
| 7 | /QH | 未接続 |
| 8 | GND | GND |
| 9 | QH | U8 → U7:SER(10) / U7 → U10:B(4) |
| 10 | SER | U8 = **GND** / U7 = U8:QH(9) |
| 15 | CLK INH（/CE） | **GND**（常時イネーブル） |
| 16 | VCC | +5V |

### 8.3 74AHCT244（U9）

| ピン | 名称 | 処理 |
|---|---|---|
| **1** | **1/OE** | **`BUS_EN_N`。未接続にしない**（浮かせると1Y1–1Y4が不定になる） |
| **19** | **2/OE** | **`BUS_EN_N`** |
| 10 | GND | GND |
| 20 | VCC | +5V |
| 15, 17 | 2A3, 2A4（未使用入力） | **GND**（浮かせない） |
| 3, 5 | 2Y3, 2Y4（未使用出力） | 未接続 |

信号の割り当ては§0の表を参照。

### 8.4 74LVC1T45（U10–U12、SOT-23-6）

| ピン | 名称 | 処理 |
|---|---|---|
| 1 | VCCA | **+3.3V** |
| 2 | GND | GND |
| 3 | A | ESP32側（出力） |
| 4 | B | 5 V側（入力） |
| 5 | DIR | **GND**（B→A固定） |
| 6 | VCCB | **+5V** |

VCCAとVCCBを取り違えると恒久的に壊れる可能性がある。実装前にテスタで確認すること。

---

## 9. 電源系統

### 9.1 レール構成

| レール | 供給元 | 供給先 | 電流目安 |
|---|---|---|---|
| `+5V`（常時） | ESP32ボードの5V / VINピン | U1–U9のVCC、U10–U12のVCCB、/SRCLR | 100〜150 mA |
| `+3.3V` | ESP32ボードの3V3ピン | U10–U12のVCCA、R23・R26–R31 | 数 mA |
| `VCC_CART` | `+5V` から SW1（またはTPS22918）経由 | **J1:30、およびカート側プルアップ R1–R16・R18–R22・R33–R34** | 60〜115 mA |

`VCC_CART` にICのVCCが入り込んでいたら誤り。逆に、カート側の信号に付くプル抵抗は**すべて** `VCC_CART` に吊ること。

### 9.2 カート電源を独立レールにする理由

**スイッチで `+5V` 全体を遮断してはいけない。** ESP32はUSBから給電されて動き続けるため、電源の落ちた74AHCT/HCTの入力ピンに3.3 Vを叩き込む状態になる。入力保護ダイオード経由でVCCラインに電流が流れ込み、ICが中途半端に起動したりラッチアップの原因になる。

**遮断するのは `VCC_CART` だけ。** U1–U9は常時給電のままにする。

### 9.3 BUS_EN_N によるバス保護（推奨）

`VCC_CART` を切っても、U1–U4とU9は5Vを出力し続けるため、今度は電源の落ちたカセット側ICへ電流が流れ込む。これを防ぐため、以下を1本のGPIOでまとめて制御する。

- U1–U4 の /OE（ピン13）
- U9 の 1/OE（ピン1）と 2/OE（ピン19）

`BUS_EN_N` = L でバス有効、H でHi-Z。R31で+3.3Vへプルアップしておくと、ESP32リセット中は自動的にHi-Zになる。

**電源シーケンス**

```
起動時： VCC_CART ON → 10 ms待機 → BUS_EN_N = L
終了時： BUS_EN_N = H → VCC_CART OFF → カセット交換
```

`BUS_EN_N` を使わない場合は、U1–U4の/OEとU9の1/OE・2/OEをGNDに直結し、カセット交換時は**基板全体の電源を落とす**運用にすること。中途半端に片方だけ切らない。

### 9.4 コンデンサ

| 種別 | 値 | 数量 | 配置 |
|---|---|---|---|
| パスコン | 0.1 µF | 12 | 各IC（U1–U12）のVCC–GND間に最短配置。PCBならIC直下の裏面 |
| バルク | 10 µF | 3 | `+5V` 入口、`+3.3V` 入口、`VCC_CART` 出口 |

AHCTは立ち上がりが速いため、**バルクコンデンサを省略しない**こと。

---

## 10. 発注チェックリスト

```
[ ] 60ピンカートリッジスロット ×2          ← 納期が長いので最優先
[ ] SN74AHCT595D（AHC ではなく AHCT を型番で確認）×8
[ ] CD74HCT165M（AHCT版は存在しない。HCTのまま）×4
[ ] SN74AHCT244D または SN74HCT244DW（「T」を確認）×2
[ ] SN74LVC1T45DBVR ×10
[ ] ESP32-WROOM-32E 開発ボード ×1（WROVERでないこと）
[ ] 抵抗 10 kΩ ×100（基板1枚あたり32本使用）
[ ] 抵抗 1 kΩ ×20
[ ] 抵抗 3.3 kΩ / 6.8 kΩ（1T45の代替を使う場合）
[ ] セラコン 0.1 µF ×30
[ ] コンデンサ 10 µF ×10
[ ] スライドスイッチ SPDT ×2
[ ] LED ×5、タクトスイッチ ×2
[ ] （TPS22918DBVR ×2、1 nF ×5：GPIO制御にする場合）
[ ] （SOT-23-6変換基板 ×5：ユニバーサル基板で組む場合）
[ ] （集合抵抗 10 kΩ×8 バス型 ×2）
```

---

## 11. ネットリストのセルフチェック

KiCadのERCでは検出できない誤りが多いため、ネットリスト出力後に以下を確認する。

### 11.1 バッファの入出力短絡

**§0の12ネットを1本ずつ確認し、各ネットにU9のノードが1つだけであることを確かめる。**

```
NG例： M2 [5] U13.26 , U9.2(1A1) , U9.18(1Y1) , J1.32 , R17
                      ~~~~~~~~~~~~~~~~~~~~~~~ 入力と出力が同じネット
OK例： M2_3.3V [3] U13.26 , U9.2(1A1) , R17
       M2_5V  [3] U9.18(1Y1) , J1.32 , R32
```

入出力が短絡すると、**ESP32のGPIOがカセットの5Vラインに直結し、GPIOが破壊される。**

### 11.2 未接続ピンの一覧を全部読む

`unconnected-` で始まるネットをすべて確認し、意図した未接続のみであることを検証する。

| 意図的に未接続でよい | 未接続にしてはいけない |
|---|---|
| U2:QH(7)、U4:QG(6)、U4:QH(7)、U4:QH'(9)、U6:QH'(9) | **U9:1/OE(1)、U9:2/OE(19)** |
| U7/U8:/QH(7)、U9:2Y3(5)、U9:2Y4(3) | **U9:2A3(15)、U9:2A4(17)**（GNDへ） |
| J1:15、31、45、46 | すべての /OE、/PL、/SRCLR、CLK INH |

### 11.3 165のビット順

§8.2の表と照合。**ピン11 = D0、ピン6 = D7**。

### 11.4 ESP32のGPIO1 / GPIO3

この2本に信号を割り当てていないことを確認する。

### 11.5 電源レール

`VCC_CART` に **ICのVCCが入り込んでいない**ことを確認する。入ってよいのは J1:30、カート側プル抵抗（R1–R16、R18–R22、R33–R34）、バルクコンデンサ、電源表示LEDのみ。

逆に、**カート側信号に付くプル抵抗が `+5V` に吊られていないか**も確認する。`+5V` 吊りだと、SW1を切っても無電源のカセットへ電流が注入され続ける。

### 11.6 レベル変換ICの入力が浮いていないか

`U11:B(4)` と `U12:B(4)` は入力ピンで、カート未挿入時は接続先が J1 のパッドだけになる。**`VCC_CART` へのプルアップ（R33 / R34）があることを確認する。** LVCの入力を浮かせると消費電流の増加と発振の原因になる。

同種の見落としを防ぐため、「片側がコネクタのパッドにしか繋がっていない入力ピン」を機械的に洗い出すとよい。

---

## 12. 組立後の確認手順

[bringup.md](bringup.md) を参照。カセットを挿す前に、アドレス線・制御線・データ線を回路単体で確認する手順になっている。

---

## 13. 既知の注意点

1. **末尾に「T」の付くHCT / AHCTを使う。** 74HC・74AHCではVIHが3.5〜3.85 Vとなり3.3Vでは動かない
2. **244の入力側と出力側を同じネット名にしない。** 短絡するとESP32のGPIOが5Vに直結して壊れる
3. **U9の1/OE(1)と2/OE(19)を未接続にしない**
4. **165のピン11 = D0、ピン6 = D7。** 逆順にすると下位ニブルだけ反転する
5. **GPIO1 / GPIO3（UART0）を使わない**
6. **U5とU6を1個にまとめない。** CPU DバスとPPU Dバスが短絡する
7. **カート電源だけを独立レールにする。** 5V全体を落とすとESP32が電源断のICへ電流を注入する
8. **OE_DATA_N / BUS_EN_N のプルアップは3.3 V。** ESP32は5Vトレラントでない
9. **244出力側のプルアップは3.3 Vではなく5 V系。** 3.3Vではカート側CMOSのVIHを満たさない
10. **カート側のプル抵抗はすべて `VCC_CART` に吊る。** `+5V` に吊ると、SW1を切っても無電源のカセットへ電流が注入される
11. **U11:B / U12:B にプルアップを付ける。** カート未挿入時に浮く
12. **GPIO16/17はWROOM-32E限定。** WROVER系では使えない
13. **1T45のVCCA / VCCBを取り違えない**
14. **244の未使用入力（2A3, 2A4）はGNDへ**
15. **ネット名に `/` を使わない**（KiCadで `{slash}` に化ける）
16. **AHCTはバルクコンデンサを省略しない**
17. **カセットの抜き差しは必ず `BUS_EN_N` = H、`VCC_CART` OFFで**
18. **165の読み出しにハードウェアSPI（MODE0）を使わない。** 先頭ビットが欠ける。ファームはビットバングで実装している（[design-notes.md](design-notes.md) §6）

---

## 改訂履歴

| 版 | 内容 |
|---|---|
| rev1 設計 | 初版。ESP32 + 74HCT595/165 + 74HCT244 構成 |
| rev1 レビュー1 | 244の入出力ネット分離、165のパラレル入力順の明示、`VCC_CART` 独立レール化、`BUS_EN_N` 追加、GPIO3（UART0 RX）の使用取りやめ |
| rev1 レビュー2 | カート側プル抵抗を `VCC_CART` へ、CIRAM 2本のプルアップ（R33/R34）追加 |
| rev1 実機 | 実機で全経路の動作確認完了。165の読み出しをビットバングに変更（ファームのみ） |

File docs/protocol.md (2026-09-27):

# シリアルプロトコル / Serial Protocol

ESP32ファーム（v3）のシリアルコマンド仕様です。

| 項目 | 値 |
|---|---|
| ボーレート | 115200 bps、8N1 |
| 改行 | `\r`、`\n`、`\r\n` のいずれでも可 |
| 大文字・小文字 | 区別しない（`e 0` = `E 0`） |
| 数値 | アドレス・データは16進（`$` や `0x` は付けない）、個数は10進 |
| 文字コード | 応答はすべてASCII |

---

## 起動時の状態

| 信号 | 状態 | 意味 |
|---|---|---|
| `BUS_EN_N` | 1 | U1〜U4、U9の出力がHi-Z。カセット側はプル抵抗で非アクティブに保持される |
| `OE_DATA_N` | 1 | U5、U6（データ書き込み用）の出力がHi-Z |
| 制御線 | 非アクティブ | M2 = 0、/ROMSEL = 1、R/W = 1、/RD = 1、/WR = 1、/A13 = 1 |

**カセットを読む前に必ず `E 0` を送ること。**

---

## コマンド一覧

### バス・信号の操作

| コマンド | 引数 | 動作 | 応答例 |
|---|---|---|---|
| `E n` | 0 / 1 | `BUS_EN_N` の設定。0 = バス有効、1 = Hi-Z | `BUS_EN_N = 0 (enabled)` |
| `A cccc pppp` | CPUアドレス（15 bit）、PPUアドレス（14 bit） | 595にアドレスを出力して保持する | `CPU A=$7FFF  PPU A=$3FFF` |
| `C name n` | 制御線名、0 / 1 | 制御線を個別に設定。名前は `M2` `ROMSEL` `RW` `RD` `WR` `A13` | `M2 = 1` |
| `I` | なし | 制御線をすべて非アクティブに戻す | `control lines idle` |

`A` のCPUアドレスは下位15 bit（A0〜A14）です。A15はコネクタに出ておらず、/ROMSELがその役割を担います。`$8000`〜`$FFFF` を読むときは `A` に `$0000`〜`$7FFF` を指定し、/ROMSELをLにします（`P` コマンドは自動でこれを行う）。

### 読み出し

| コマンド | 引数 | 動作 | 応答例 |
|---|---|---|---|
| `R` | なし | 165に現在のデータバスをロードして読む | `CPU D=FF  PPU D=FF` |
| `G` | なし | CIRAM A10、CIRAM /CE を読む | `CIRAM_A10=1  CIRAM_CE_N=1` |
| `V` | なし | CPUの割り込みベクタ（`$FFFA`〜`$FFFF`）を読んで判定 | 下記 |
| `P aaaa [n]` | 開始アドレス（`$8000`〜`$FFFF`）、バイト数（省略時16） | PRG-ROMの16進ダンプ | `8000: 78 D8 A9 10 …` |
| `H aaaa [n]` | 開始アドレス（`$0000`〜`$1FFF`）、バイト数（省略時16） | CHR-ROMの16進ダンプ | `0000: 03 0F 1F 1F …` |
| `M` | なし | ミラーリング判定 | 下記 |
| `D` | なし | 全領域のバイナリダンプ（PC側スクリプト用） | 下記 |

### 設定

| コマンド | 引数 | 動作 |
|---|---|---|
| `S n` | µs（1以上） | シフトクロックの半周期。既定値1 µs。接点が不安定なときに大きくする |
| `?` | なし | コマンド一覧を表示 |

---

## `V`：ベクタ読み出し

```
NMI   $FFFA = $8082 [OK]
RESET $FFFC = $8000 [OK]
IRQ   $FFFE = $FFF0 [OK]
```

6502は電源投入時に `$FFFC`/`$FFFD` を読んで開始番地とするため、正常なカセットなら値は必ず `$8000` 以上になります。外部の正解データなしに、回路が正しく読めているかを自己判定できます。

---

## `M`：ミラーリング判定

PPUアドレスを `$2000`、`$2400`（PA10 = 1）、`$2800`（PA11 = 1）の順に出力し、カセットが返すCIRAM A10を読みます。

| CIRAM A10 の追従先 | 判定 | 表示 |
|---|---|---|
| PA10 | 垂直ミラー | `VERTICAL (follows PA10)` |
| PA11 | 水平ミラー | `HORIZONTAL (follows PA11)` |
| どちらでもない | 1画面 / 4画面 / 配線異常 | `UNKNOWN` |

NROMのカセットでは、CIRAM A10はカセット基板上でPA10かPA11に直結されているため、この方法で判定できます。

---

## `D`：バイナリダンプ

PC側スクリプト（`tools/dump_nes.py`）が使うコマンドです。シリアルモニタで送ると、バイナリがそのまま表示されて画面が乱れます。

### 送信形式

```
DUMP prg=<PRGサイズ> chr=<CHRサイズ> mir=<V|H|?>\n
<PRGデータ（prgバイト）>
<CHRデータ（chrバイト）>
\n
END crc=<8桁16進>\n
```

| フィールド | 内容 |
|---|---|
| `prg` | 16384 または 32768 |
| `chr` | 8192（固定） |
| `mir` | `V`（垂直）、`H`（水平）、`?`（判定不能） |
| `crc` | PRGデータとCHRデータを連結したものの CRC-32（IEEE 802.3、zlibと同一） |

### ファーム内の処理

1. `$8000`〜`$FFFF` の32 KBを読んでRAMに格納
2. PPU `$0000`〜`$1FFF` の8 KBを読んでRAMに格納
3. ミラーリングを判定
4. PRGの前半16 KBと後半16 KBを比較し、一致すれば16 KB品（NROM-128）と判定。この場合は `$C000`〜`$FFFF` 側の16 KBを送る
5. CRC-32を計算して送信

NROM-128のカセットはA14を使わないため、`$8000`〜`$BFFF` と `$C000`〜`$FFFF` に同じ内容が見えます。

所要時間は、読み出し約5秒、転送約4秒です（32 KB + 8 KB の場合）。

---

## PC側の処理（`tools/dump_nes.py`）

1. ポートを開く（DTR/RTSをLにして、ESP32の自動リセットを避ける）
2. `E 0` を送る
3. `D` で1回目のダンプ。CRCを照合
4. `D` で2回目のダンプ。CRCを照合
5. `E 1` を送る
6. 2回の結果（PRG、CHR、ミラーリング）が完全一致した場合のみ、iNESヘッダを付けて保存

### 生成するiNESヘッダ（16バイト）

| オフセット | 値 | 内容 |
|---|---|---|
| 0〜3 | `4E 45 53 1A` | `"NES"` + `$1A` |
| 4 | PRGサイズ ÷ 16384 | 1 または 2 |
| 5 | CHRサイズ ÷ 8192 | 1 |
| 6 | `$01`（垂直）/ `$00`（水平） | bit 0 = ミラーリング、上位4 bit = マッパー番号下位（0） |
| 7 | `$00` | マッパー番号上位（0） |
| 8〜15 | `$00` | 未使用 |

---

## 終了コード（`dump_nes.py`）

| コード | 意味 |
|---|---|
| 0 | 成功 |
| 1 | 引数エラー |
| 2 | 2回のダンプが一致しない |
| 例外終了 | 応答なし、CRC不一致、受信バイト不足 |

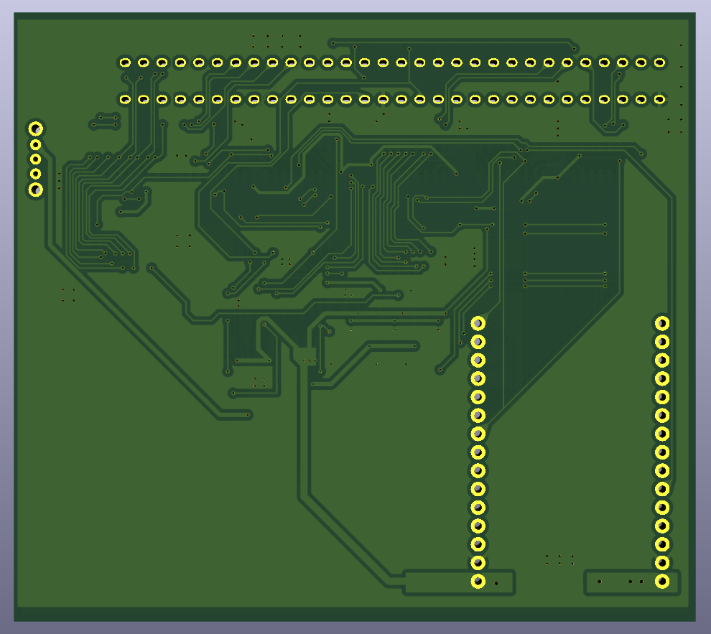
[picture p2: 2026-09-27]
images/3Dmodel_2.png

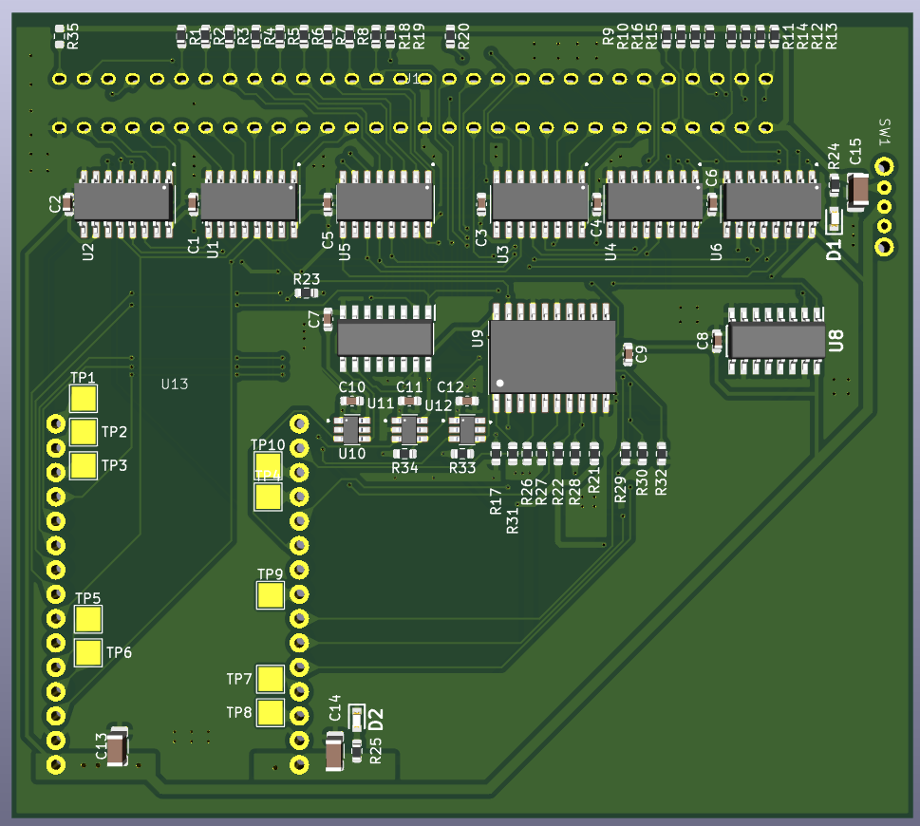
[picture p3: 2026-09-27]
images/3Dmodel_1.png

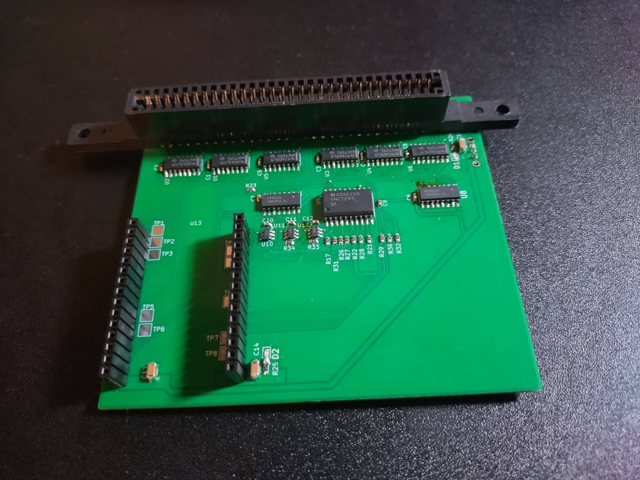
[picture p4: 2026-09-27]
images/現物.jpg

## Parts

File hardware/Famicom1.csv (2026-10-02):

Reference | Qty | Value | DNP | Exclude from BOM | Exclude from Board | Exclude from Simulation | Exclude from Position Files | Footprint | Datasheet
C1,C2,C3,C4,C5,C6,C7,C8,C9,C10,C11,C12 | 12 | GRM188F11H104ZA01 |  |  |  |  | ${EXCLUDE_FROM_POS_FILES} | Capacitor_SMD:C_0603_1608Metric
C13,C14,C15 | 3 | GRM31CB31H106KA12 |  |  |  |  | ${EXCLUDE_FROM_POS_FILES} | Capacitor_SMD:C_1206_3216Metric
D1,D2 | 2 | SML-E12P8WT86 |  |  |  |  | ${EXCLUDE_FROM_POS_FILES} | 0_Library:SML-E12P8WT86
J1 | 1 |  |  |  |  |  | ${EXCLUDE_FROM_POS_FILES} | 0_Library:FamilyComputer_60pin
R1,R2,R3,R4,R5,R6,R7,R8,R9,R10,R11,R12,R13,R14,R15,R16,R17,R18,R19,R20,R21,R22,R23,R26,R27,R28,R29,R30,R31,R32,R33,R34 | 32 | RK73B1JTTD103J |  |  |  |  | ${EXCLUDE_FROM_POS_FILES} | Resistor_SMD:R_0603_1608Metric
R24,R25 | 2 | RK73B1JTTD102J |  |  |  |  | ${EXCLUDE_FROM_POS_FILES} | Resistor_SMD:R_0603_1608Metric
R35 | 1 | RK73Z1JTTD | 未実装(DNP) |  |  |  | ${EXCLUDE_FROM_POS_FILES} | Resistor_SMD:R_0603_1608Metric
SW1 | 1 | SK-12D11VG3 |  |  |  |  | ${EXCLUDE_FROM_POS_FILES} | 0_Library:SK-12D11VG3
TP1,TP2,TP3,TP4,TP5,TP6,TP7,TP8,TP9,TP10 | 10 | TestPoint |  |  |  |  | ${EXCLUDE_FROM_POS_FILES} | TestPoint:TestPoint_Pad_2.5x2.5mm
U1,U2,U3,U4,U5,U6 | 6 | SN74AHCT595D |  |  |  |  | ${EXCLUDE_FROM_POS_FILES} | 0_Library:SN74AHCT595D
U7,U8 | 2 | CD74HCT165M96 |  |  |  |  | ${EXCLUDE_FROM_POS_FILES} | 0_Library:CD74HCT165M96 | http://www.ti.com/lit/ds/symlink/cd74hct165.pdf
U9 | 1 | SN74AHCT244DWR |  |  |  |  | ${EXCLUDE_FROM_POS_FILES} | 0_Library:SN74AHCT244DWR
U10,U11,U12 | 3 | SN74LVC1T45DBVR |  |  |  |  | ${EXCLUDE_FROM_POS_FILES} | 0_Library:SN74LVC1T45DBVR
U13 | 1 | ESP32_DevModule |  |  |  |  | ${EXCLUDE_FROM_POS_FILES} | 0_Library:ESP32_DevModule

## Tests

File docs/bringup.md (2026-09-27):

# 立ち上げ手順 / Bring-up Guide

部品を実装した基板を、はじめてカセットを吸い出してMesenでゲームが起動するところまで確認する手順です。

**カセットを挿すのはStep 4からです。** Step 0〜3で、アドレス線・制御線・データ線を回路単体で確認します。いきなりカセットを挿すと、読めなかったときに原因がカセットなのか回路なのか切り分けられません。

配線の詳細は [hardware.md](hardware.md)、コマンドの詳細は [protocol.md](protocol.md) を参照してください。

---

## 必要なもの

| 種類 | 内容 |
|---|---|
| 工具 | テスタ（電圧・導通・抵抗） |
| 部品 | 1 kΩ抵抗 1本（Step 3でジャンパー線の代わりに使う。無くても可） |
| カセット | **Mapper 0（NROM）のファミコンカセット**。スーパーマリオブラザーズ（PRG 32 KB）を推奨 |
| PCソフト | VS Code + PlatformIO、Python 3、MesenCE |

### 最初のカセットにNROMを使う理由

NROMはバンク切替がないので、アドレスを出して読むだけで全領域が読めます。MMC1やMMC3のカセットは、専用レジスタへの書き込みなしでは全領域を読めず、最初の確認には向きません。

PRGが32 KBのカセット（スーパーマリオブラザーズ等）は、アドレス線をA14まですべて使います。16 KB品（ドンキーコング等）はカセット側でA14を使わないため、A14の配線不良を見逃します。

---

## Step 0：通電前の確認

ESP32ボードを挿さずに、テスタで確認します。

| 確認 | 合格条件 |
|---|---|
| `+5V`–GND、`+3.3V`–GND、`VCC_CART`–GND の抵抗 | 短絡していない（数百Ω以上） |
| `+5V`–`+3.3V` の抵抗 | 短絡していない |
| IC 12個の1番ピンの向き | シルクと一致 |
| U10〜U12（74LVC1T45、SOT-23-6）の向き | 逆だとVCCA/VCCBが入れ替わって壊れる |

---

## Step 1：ファームの書き込み

1. VS Codeで `firmware/` フォルダを開く（`platformio.ini` のあるフォルダ）
2. SW1 OFF、カセット未挿入でESP32ボードをUSB接続
3. PlatformIOのUpload（→）を実行

`Connecting......` で止まる場合は、ESP32ボードのBOOTボタンを押しながら書き込みを開始してください。

書き込み後、Serial Monitor（コンセントのアイコン）を開くと以下が表示されます。表示されなければENボタンを1回押してください。

```
Famicom Dumper v3 (bit-bang + dump). BUS_EN_N=1 (Hi-Z) at boot
```

`?` を送るとコマンド一覧が表示されます。

---

## Step 2：電源の確認

テスタで測ります。

1. SW1 OFFで、J1:30（`VCC_CART`）が0 V
2. **このとき各ICのVCC（U1〜U9）は5 Vのまま**であること。0 Vになるなら、カセット電源が独立レールになっていない
3. SW1 ONで、J1:30が5 V、LED D1が点灯
4. U10〜U12のVCCAが3.3 V、VCCBが5 V

---

## Step 3：アドレス線の確認（カセット未挿入）

> ⚠️ **ESP32の起動直後はバスがHi-Z（`BUS_EN_N` = 1）です。最初に必ず `E 0` を送ってください。**
> Hi-Zのままだと、カセット側の線はプル抵抗の電圧になり、コマンドを送っても変化しません。書き込み直しやリセットのたびに `E 0` が必要です。

J1のはんだ面をテスタで測ります（コネクタの中は奥まっていてプローブが当てにくいため）。

```
E 0
A 5555 1555
A 2AAA 2AAA
```

アドレス29本（J1のピン2〜13、33〜35、19〜25、50〜56）が、2つのパターンで0 V / 5 Vが反転すれば合格です。この2パターンで、固着・隣接ピンのブリッジ・ビットの取り違えをすべて検出できます。

| コマンド | 出力されるパターン |
|---|---|
| `A 5555 1555` | A0、A2、A4 … が5 V、A1、A3 … が0 V |
| `A 2AAA 2AAA` | 上の反転 |

出力は次のコマンドを送るまで保持されるので、1本ずつ測って構いません。

---

## Step 4：制御線の確認（カセット未挿入、SW1 ON）

```
E 0
C M2 1       → J1:32 = 5 V      C M2 0      → 0 V
C ROMSEL 0   → J1:44 = 0 V      C ROMSEL 1  → 5 V
C RW 0       → J1:14 = 0 V      C RW 1      → 5 V
C RD 0       → J1:17 = 0 V      C RD 1      → 5 V
C WR 0       → J1:47 = 0 V      C WR 1      → 5 V
C A13 0      → J1:49 = 0 V      C A13 1     → 5 V
I
```

**0 Vに落ちることを必ず確認してください。** `E 0` を忘れていると、M2以外の5本はプル抵抗で5 Vのままなので、正常に見えてしまいます（M2だけはプルダウンなので0 Vのままになり、異常に見えます）。

---

## Step 5：データ線の確認（カセット未挿入、SW1 ON）

> ⚠️ **SW1をONにしてから行ってください。** データ線のプルアップは `VCC_CART` に接続されているので、SW1 OFFではデータ線が浮き、テスタでは2〜3 V程度の意味のない値が見えます。

```
R   → CPU D=FF  PPU D=FF
G   → CIRAM_A10=1  CIRAM_CE_N=1
```

### ビット順の確認（任意）

1 kΩ抵抗の片足をGND（J1:1か16）に、もう片足をJ1の各データピンのはんだ面に当てて `R` を送ります。

| 当てるピン | 期待値 |
|---|---|
| 43（CPU D0） | `CPU D=FE` |
| 36（CPU D7） | `CPU D=7F` |
| 26（PPU D0） | `PPU D=FE` |
| 57（PPU D7） | `PPU D=7F` |

1 kΩを使うと、10 kΩのプルアップとの分圧で 5 V × 1 / (10 + 1) = 0.45 V になり、HCT165のVIL（0.8 V）を下回るので確実にLと読まれます。直接GNDに短絡させるのと違い電流が約0.45 mAに制限されるので、当てる場所を間違えても壊れません。

この確認を省略しても、Step 6のカセットの中身でビット順を確認できます。

---

## Step 6：カセットの読み出し

### カセットの向き

**ラベル面が、J1のピン1〜30側**です。ラベル面を手前にして端子を下に向けたとき、左端がピン1（GND）、右端がピン30（+5V）です。

逆に挿すと電源とGNDが違うピンに入ってカセットを壊すおそれがあるので、初回は以下で確認してください。

1. **カセット側**：テスタの導通モードで、ラベル面の左から1本目と16本目を当てる → 導通あり（どちらもGND）
2. **基板側**：J1のピン1のパッド（四角いパッド）がある列を確認する。カセットのラベル面をその列の側に向ける

### 挿入手順

```
E 1 → SW1 OFF → カセット挿入 → SW1 ON → E 0
```

SW1 ONでLED D1が点灯することを確認します。点灯しない、またはUSBの電流が急増する場合は、すぐにSW1をOFFにして向きを確認し直してください。

### 読み出し確認

```
V
P 8000 16
M
H 0000 16
```

スーパーマリオブラザーズでの実測値：

```
NMI   $FFFA = $8082 [OK]
RESET $FFFC = $8000 [OK]
IRQ   $FFFE = $FFF0 [OK]
8000: 78 D8 A9 10 8D 00 20 A2 FF 9A AD 02 20 10 FB AD
CIRAM A10: base=0 PA10=1 PA11=0 -> VERTICAL (follows PA10)
0000: 03 0F 1F 1F 1C 24 26 66 00 00 00 00 1F 3F 3F 7F
```

| コマンド | 確認していること | 合格の目安 |
|---|---|---|
| `V` | CPUアドレス線、/ROMSEL、M2、CPUデータ線 | 3行とも `[OK]`（$8000以上） |
| `P 8000 16` | ビット順 | 先頭が `78 D8`（SEI、CLD）。ほとんどのファミコンソフトはこの2命令で始まる |
| `M` | PPUアドレス線（A10/A11/A13）、CIRAM A10 | カセットの仕様どおり（SMBはVERTICAL） |
| `H 0000 16` | PPUアドレス線、PPU /RD、PPUデータ線 | `FF` 以外の値が混ざる |

### カセットを抜くとき

```
E 1 → SW1 OFF → カセットを抜く
```

`E 1` を忘れて抜くと、電源の落ちたカセットにアドレス線の5 Vが加わります。

---

## Step 7：PCへダンプして `.nes` を作る

### Python環境の準備（初回のみ）

```
python -m venv ESP32_Famicom
ESP32_Famicom\Scripts\activate
pip install pyserial
```

VS Codeで「Pythonパッケージをグローバル環境にインストールしている可能性があります」と通知が出ることがありますが、プロンプトの先頭に `(ESP32_Famicom)` と出ていれば仮想環境に入っているので無視して構いません。

### ダンプ

1. **PlatformIOのシリアルモニタを閉じる**（ポートを占有するため）
2. カセットを挿してSW1 ON
3. 実行：

```
python tools/dump_nes.py COM5 smb.nes
```

`COM5` はESP32のポート番号に置き換えてください。スクリプトが開始時に `E 0`、終了時に `E 1` を自動で送るので、手動操作は不要です。

```
BUS_EN_N = 0 (enabled)
pass 1: PRG 32KB  CHR 8KB  mirror=V  CRC32=D445F698  (11.5s)
pass 2: CRC32=D445F698
BUS_EN_N = 1 (Hi-Z)
OK: smb.nes (40976 bytes)  PRG+CHR CRC32=D445F698
```

4. 終わったらSW1 OFF → カセットを抜く

スクリプトは2回ダンプして完全一致した場合のみ保存します。一致しない場合は、カセットの端子を無水エタノールと綿棒で清掃してから挿し直してください（消しゴムは金メッキを削るので使わない）。

> 吸い出したROMファイルは、このリポジトリのフォルダの外に保存することを勧めます。誤ってGitHubにアップロードしないためです。

---

## Step 8：Mesenで起動

1. [MesenCE](https://github.com/nesdev-org/MesenCE)（Mesen 2の後継）をダウンロードする。Windows 10/11はネイティブ版（.NETランタイム不要）でよい
2. 起動して、`smb.nes` をウィンドウにドラッグ＆ドロップ
3. タイトル画面が出て、1-1がプレイできれば完了

**ゲームが最後まで正しく表示されることが、ダンプが1バイトも化けていないことの最終確認です。** 背景やキャラクターの絵が崩れていないか、しばらく遊んで確認してください。

---

## トラブルシューティング

| 症状 | 原因 | 対処 |
|---|---|---|
| コマンドを送っても電圧が変わらない | `E 0` を送っていない | 起動・リセットのたびに `E 0` |
| M2だけ5 Vにならない | 同上（M2だけプルダウンのため目立つ） | `E 0` |
| データ線が2〜3 V | SW1 OFFでプルアップが無効 | SW1 ON |
| `R` が常に `00 00` | SW1 OFF、またはU10の向き・VCCA/VCCB | SW1確認、U10確認 |
| `R` が常に `FF FF`（GNDに落としても不変） | /PL（GPIO33）、165のCLK INH（ピン15）の未接続 | はんだ確認 |
| `R` が `FF FE` | 165の先頭ビット欠落（ハードウェアSPI MODE0使用時） | v2以降のファーム（ビットバング）を使う |
| `V` で `$FFFF` | `E 0` 忘れ、端子の汚れ、差し込みが浅い | `E 0`、端子清掃、挿し直し |
| `V` の値が毎回変わる | 接点不良、ノイズ | 挿し直し、`S 5` でシフトクロックを遅くする |
| 値は安定しているが `78 D8` にならない | アドレス線の不良、ビット順 | Step 3・5をやり直す |
| `could not open port` | シリアルモニタが開いたまま | モニタを閉じる |
| `NG: 2回のダンプが一致しません` | 接点不良 | 端子清掃・挿し直し |
| `CRC mismatch` | USBシリアル転送の化け | ケーブル交換、USBハブを避ける |
| 書き込みが `Connecting......` で止まる | ESP32が書き込みモードに入らない | BOOTボタンを押しながら書き込み |

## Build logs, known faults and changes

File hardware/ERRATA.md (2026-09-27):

# ERRATA — rev1

rev1基板の既知の問題と、次版での修正予定です。**いずれもrev1の動作には影響しません**（rev1でスーパーマリオブラザーズの吸い出し・Mesenでの起動を確認済み）。

| # | 内容 | 影響 | rev1での回避策 | 次版での修正 |
|---|---|---|---|---|
| 1 | J1ピン15のシンボル名が `/GRQ`（正しくは `/IRQ`） | なし（工程1では未使用ピン） | なし | ライブラリのシンボル名を修正 |
| 2 | J1ピン31（CartridgePresent または +5V、カセットにより異なる）の切り替え用ソルダージャンパがない | 一部のカセットで読めない可能性（未確認） | 必要になったら、J1:31と `VCC_CART` をジャンパー線で接続 | ソルダージャンパまたは未実装0 Ωのパターンを追加 |
| 3 | LED D1が `VCC_CART` 側にあり、常時電源（`+5V`）の表示がない | 通電しているかがSW1 OFF時に分からない | ESP32ボードの電源LEDで確認 | `+5V` 側に電源表示LEDを追加 |
| 4 | ハードウェアSPI（MODE0）で74HCT165を読むと先頭ビットが欠ける | 読み出し値が1ビットずれる | ファームをビットバングで実装（v2以降） | 基板変更不要。詳細は [../docs/design-notes.md](../docs/design-notes.md) §6 |

<!-- 以下は必要に応じて記入 -->
<!-- | 5 | R33/R34（CIRAMプルアップ）： rev1基板への反映状況 | | | | -->

## 動作確認済みの条件

| 項目 | 内容 |
|---|---|
| ファーム | v3（ビットバング + `D` コマンド） |
| カセット | スーパーマリオブラザーズ（NROM-256、垂直ミラー） |
| 結果 | PRG 32 KB + CHR 8 KB を2回ダンプして一致、MesenCEで起動・プレイ確認 |

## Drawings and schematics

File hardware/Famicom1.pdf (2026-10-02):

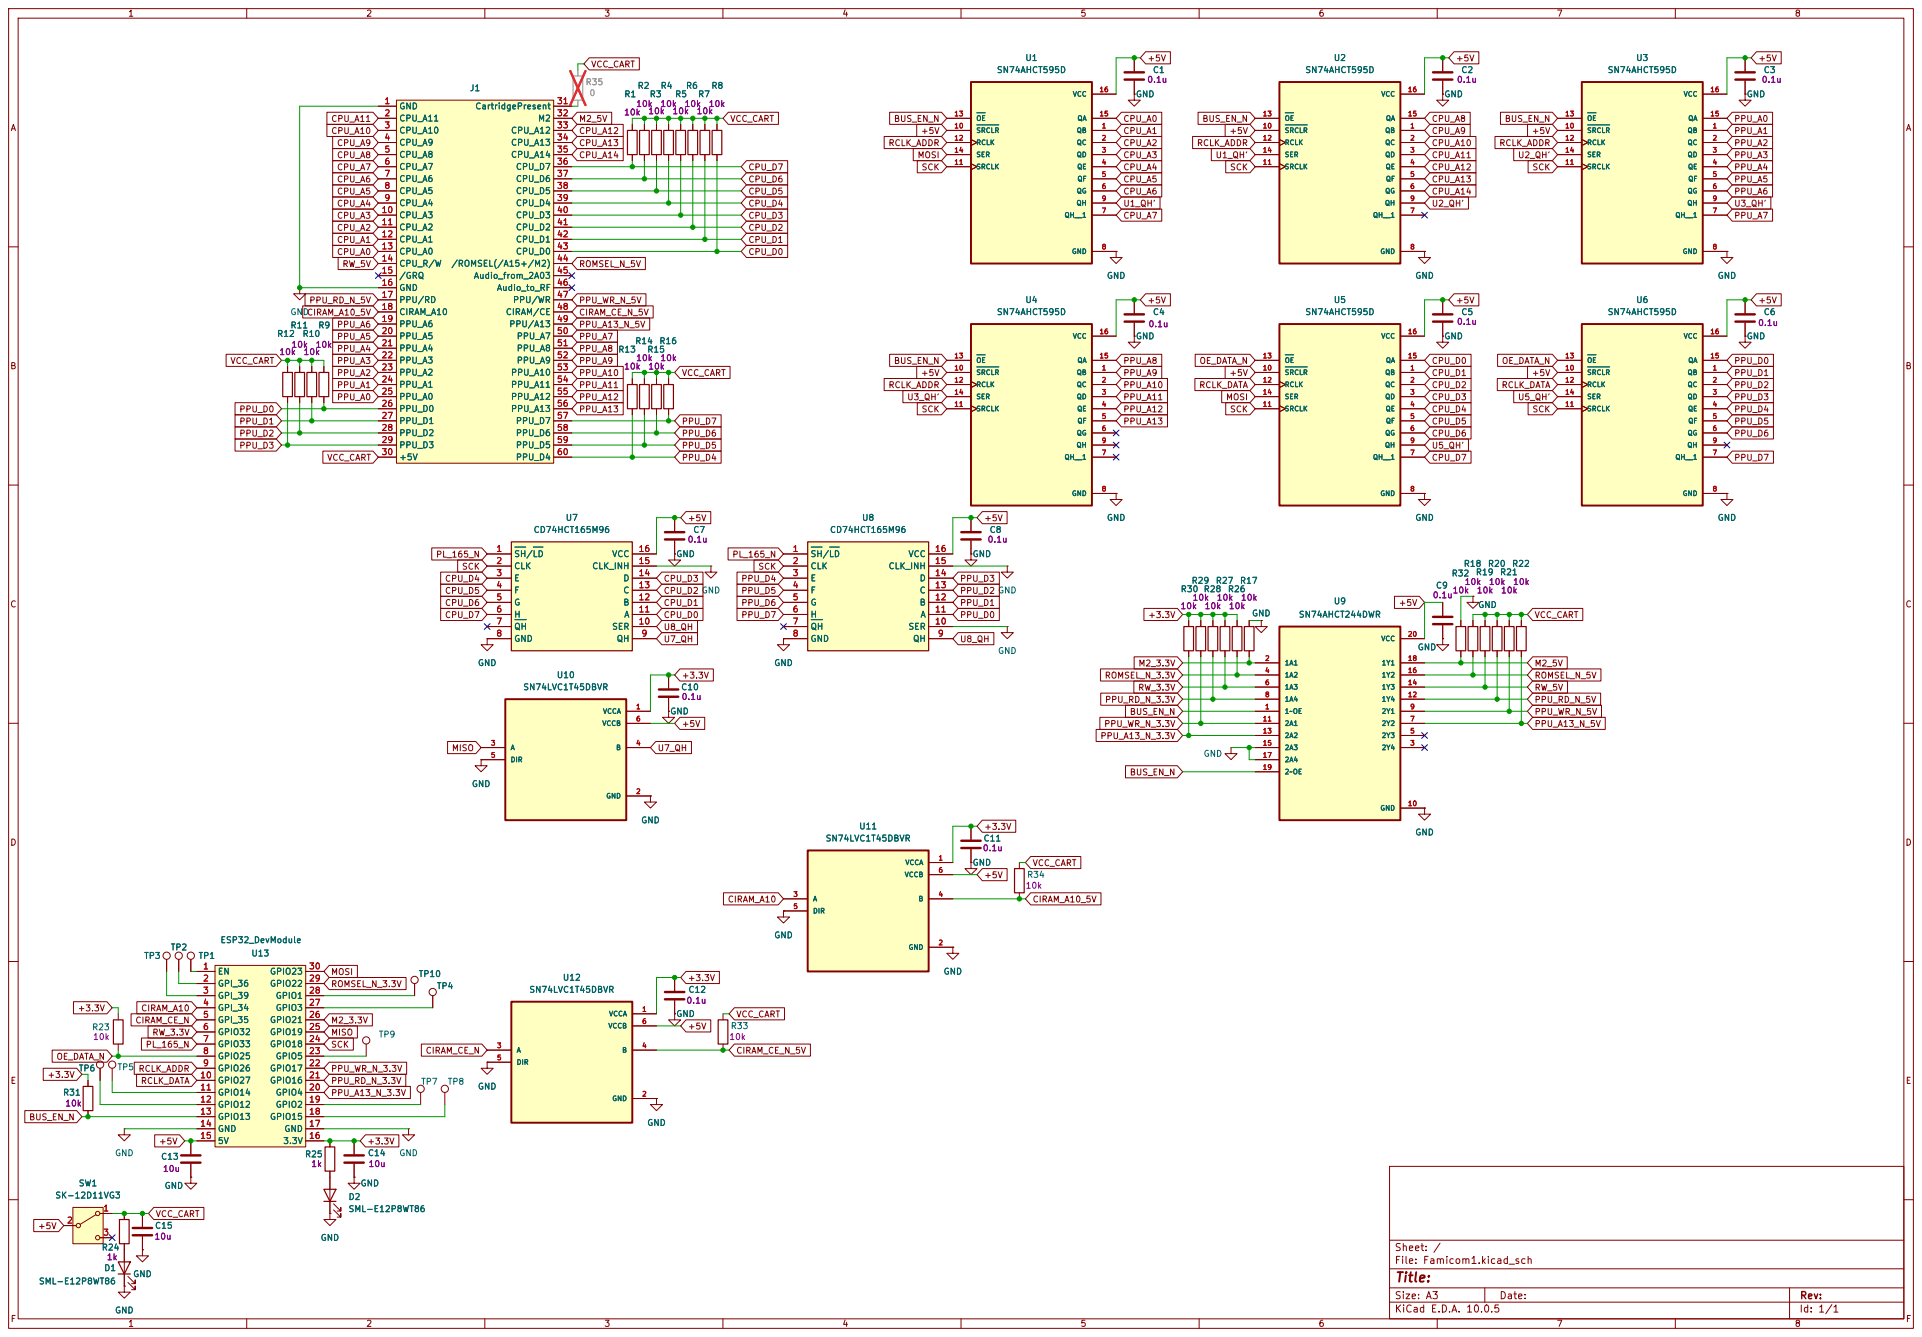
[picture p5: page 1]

Size: A3 | Rev: | F Date:
KiCad E.D.A. 10.0.5 | Id: 1/1

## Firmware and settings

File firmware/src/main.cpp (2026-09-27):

// Famicom ROM Dumper - Bring-up firmware (Hardware.md rev4 準拠)
// シリアル 115200bps。"?" でコマンド一覧。
//
// v2: ハードウェアSPIをやめてビットバングに変更。
//   74HC165 は /PL 直後に QH へ最初のビット(H)を出し、CP の立ち上がりでシフトする。
//   SPI MODE0 は同じ立ち上がりでサンプルするため、ESP32 の入力遅延により
//   シフト後の値を読んで先頭ビットを失う（CPU D7 が消え、末尾に U8:SER=GND の 0 が入る）。
//   ビットバングで「読む → クロック」の順を明示して回避する。
#include <Arduino.h>

// ---- ピン割り当て（Hardware.md §5）----
constexpr int PIN_SCK = 18, PIN_MOSI = 23, PIN_MISO = 19;
constexpr int PIN_RCLK_ADDR = 26, PIN_RCLK_DATA = 27, PIN_OE_DATA_N = 25;
constexpr int PIN_PL_165_N  = 33;
constexpr int PIN_M2 = 21, PIN_ROMSEL_N = 22, PIN_RW = 32;
constexpr int PIN_PPU_RD_N = 16, PIN_PPU_WR_N = 17, PIN_PPU_A13_N = 4;
constexpr int PIN_CIRAM_A10 = 34, PIN_CIRAM_CE_N = 35;
constexpr int PIN_BUS_EN_N = 13;

uint32_t clkDelayUs = 1;               // シフトクロックの H/L 各幅

inline void sclk() {                   // SCK 立ち上がりで 595/165 ともにシフト
  digitalWrite(PIN_SCK, HIGH);
  delayMicroseconds(clkDelayUs);
  digitalWrite(PIN_SCK, LOW);
  delayMicroseconds(clkDelayUs);
}

void shiftOutByte(uint8_t b) {         // MSB first: bit7 -> QH
  for (int i = 7; i >= 0; i--) {
    digitalWrite(PIN_MOSI, (b >> i) & 1);
    sclk();
  }
}

uint8_t shiftInByte() {                // QH を読んでからクロック
  uint8_t v = 0;
  for (int i = 0; i < 8; i++) {
    v = (v << 1) | digitalRead(PIN_MISO);
    sclk();
  }
  return v;
}

// ---------------------------------------------------------------
void idleBus() {                       // 全制御線を非アクティブ側へ
  digitalWrite(PIN_M2, LOW);
  digitalWrite(PIN_ROMSEL_N, HIGH);
  digitalWrite(PIN_RW, HIGH);
  digitalWrite(PIN_PPU_RD_N, HIGH);
  digitalWrite(PIN_PPU_WR_N, HIGH);
  digitalWrite(PIN_PPU_A13_N, HIGH);
}

void setAddr(uint16_t cpuA, uint16_t ppuA) {
  uint8_t buf[4] = {
    (uint8_t)((ppuA >> 8) & 0x3F),     // U4: PPU A13..A8
    (uint8_t)( ppuA       & 0xFF),     // U3: PPU A7..A0
    (uint8_t)((cpuA >> 8) & 0x7F),     // U2: CPU A14..A8
    (uint8_t)( cpuA       & 0xFF)      // U1: CPU A7..A0
  };
  for (uint8_t b : buf) shiftOutByte(b);
  digitalWrite(PIN_RCLK_ADDR, HIGH);
  digitalWrite(PIN_RCLK_ADDR, LOW);
}

// 165 に現在のバス値をロードして 16bit 読む。戻り値: 上位=CPU D, 下位=PPU D
uint16_t read165() {
  digitalWrite(PIN_PL_165_N, LOW);
  delayMicroseconds(1);
  digitalWrite(PIN_PL_165_N, HIGH);
  delayMicroseconds(1);
  uint8_t cpuD = shiftInByte();        // U7 が先
  uint8_t ppuD = shiftInByte();        // U8
  return (uint16_t)cpuD << 8 | ppuD;
}

uint8_t readPrg(uint16_t addr) {       // addr: $8000-$FFFF
  setAddr(addr & 0x7FFF, 0x0000);
  digitalWrite(PIN_RW, HIGH);
  digitalWrite(PIN_M2, HIGH);
  digitalWrite(PIN_ROMSEL_N, LOW);
  delayMicroseconds(2);
  uint8_t v = read165() >> 8;
  digitalWrite(PIN_ROMSEL_N, HIGH);
  digitalWrite(PIN_M2, LOW);
  return v;
}

uint8_t readChr(uint16_t addr) {       // addr: $0000-$1FFF
  setAddr(0x0000, addr & 0x1FFF);      // PA13 = 0
  digitalWrite(PIN_PPU_A13_N, HIGH);
  digitalWrite(PIN_PPU_RD_N, LOW);
  delayMicroseconds(2);
  uint8_t v = read165() & 0xFF;
  digitalWrite(PIN_PPU_RD_N, HIGH);
  return v;
}

// ---------------------------------------------------------------
void help() {
  Serial.println(F(
    "\n--- Step0-2: no cartridge ---\n"
    " E 0|1        BUS_EN_N (0=enable, 1=Hi-Z)\n"
    " A cccc pppp  set address (CPU 15bit, PPU 14bit) ex: A 7FFF 3FFF\n"
    " C n 0|1      control line n: M2 ROMSEL RW RD WR A13\n"
    " I            all control lines inactive\n"
    "--- Step3: no cartridge, SW1 ON ---\n"
    " R            raw 165 read (CPU D / PPU D)\n"
    " G            read CIRAM A10 / CIRAM /CE\n"
    " S n          shift clock half-period [us] (default 1)\n"
    "--- Step4: cartridge inserted, SW1 ON ---\n"
    " V            vectors ($FFFA-$FFFF)\n"
    " P aaaa [n]   PRG dump ex: P FFF0 16\n"
    " H aaaa [n]   CHR dump ex: H 0000 16\n"
    " M            mirroring check\n"
    " D            full NROM dump (binary; use dump_nes.py)"));
}

void dumpLine(uint16_t base, const uint8_t* d, int n) {
  Serial.printf("%04X:", base);
  for (int i = 0; i < n; i++) Serial.printf(" %02X", d[i]);
  Serial.println();
}

void cmdVector() {
  const char* name[] = {"NMI  ", "RESET", "IRQ  "};
  for (int i = 0; i < 3; i++) {
    uint16_t a = 0xFFFA + i * 2;
    uint16_t v = readPrg(a) | (uint16_t)readPrg(a + 1) << 8;
    Serial.printf("%s $%04X = $%04X %s\n", name[i], a, v,
                  v >= 0x8000 ? "[OK]" : "[NG]");
  }
}

void cmdMirror() {
  setAddr(0, 0x2000 | 0x0400);  // PA10=1, PA11=0
  int a10_1 = digitalRead(PIN_CIRAM_A10);
  setAddr(0, 0x2000 | 0x0800);  // PA10=0, PA11=1
  int a11_1 = digitalRead(PIN_CIRAM_A10);
  setAddr(0, 0x2000);
  int base  = digitalRead(PIN_CIRAM_A10);
  Serial.printf("CIRAM A10: base=%d PA10=%d PA11=%d -> ", base, a10_1, a11_1);
  if (base == 0 && a10_1 == 1 && a11_1 == 0)      Serial.println("VERTICAL (follows PA10)");
  else if (base == 0 && a10_1 == 0 && a11_1 == 1) Serial.println("HORIZONTAL (follows PA11)");
  else                                            Serial.println("UNKNOWN (1-screen / 4-screen / wiring fault)");
}

// ---- 全ダンプ (NROM) ----------------------------------------------
static uint8_t romBuf[0x8000 + 0x2000];          // PRG 32KB + CHR 8KB

uint32_t crc32(const uint8_t* d, size_t n, uint32_t c = 0xFFFFFFFF) {
  for (size_t i = 0; i < n; i++) {
    c ^= d[i];
    for (int k = 0; k < 8; k++) c = (c >> 1) ^ (0xEDB88320 & -(c & 1));
  }
  return c;
}

char detectMirror() {                  // 'V' / 'H' / '?'
  setAddr(0, 0x2000);          int base = digitalRead(PIN_CIRAM_A10);
  setAddr(0, 0x2000 | 0x0400); int a10  = digitalRead(PIN_CIRAM_A10);
  setAddr(0, 0x2000 | 0x0800); int a11  = digitalRead(PIN_CIRAM_A10);
  if (base == 0 && a10 == 1 && a11 == 0) return 'V';
  if (base == 0 && a10 == 0 && a11 == 1) return 'H';
  return '?';
}

// プロトコル: "DUMP prg=<n> chr=<n> mir=<c>\n" + PRG + CHR + "END crc=<hex>\n"
void cmdDump() {
  uint8_t* prg = romBuf;
  uint8_t* chr = romBuf + 0x8000;
  for (uint32_t i = 0; i < 0x8000; i++) {
    prg[i] = readPrg(0x8000 + i);
    if ((i & 0x3FF) == 0) delay(0);    // 1KBごとに他タスクへ譲る (WDT対策)
  }
  for (uint32_t i = 0; i < 0x2000; i++) {
    chr[i] = readChr(i);
    if ((i & 0x3FF) == 0) delay(0);
  }
  char mir = detectMirror();

  // NROM-128 判定: 前半16KBと後半16KBが一致すれば 16KB 品
  size_t prgSize = memcmp(prg, prg + 0x4000, 0x4000) == 0 ? 0x4000 : 0x8000;
  const uint8_t* prgOut = (prgSize == 0x4000) ? prg + 0x4000 : prg;  // $C000側を採用

  uint32_t c = crc32(prgOut, prgSize);
  c = ~crc32(chr, 0x2000, c);

  Serial.printf("DUMP prg=%u chr=%u mir=%c\n", (unsigned)prgSize, 0x2000u, mir);
  Serial.flush();
  Serial.write(prgOut, prgSize);
  Serial.write(chr, 0x2000);
  Serial.flush();
  Serial.printf("\nEND crc=%08X\n", (unsigned)c);
}

void setCtrl(const String& n, int v) {
  int pin = -1;
  if      (n == "M2")     pin = PIN_M2;
  else if (n == "ROMSEL") pin = PIN_ROMSEL_N;
  else if (n == "RW")     pin = PIN_RW;
  else if (n == "RD")     pin = PIN_PPU_RD_N;
  else if (n == "WR")     pin = PIN_PPU_WR_N;
  else if (n == "A13")    pin = PIN_PPU_A13_N;
  if (pin < 0) { Serial.println("bad control line name"); return; }
  digitalWrite(pin, v);
  Serial.printf("%s = %d\n", n.c_str(), v);
}

void handle(String line) {
  line.trim(); line.toUpperCase();
  if (line.isEmpty()) return;
  char c = line[0];
  String a1, a2;
  int sp1 = line.indexOf(' ');
  if (sp1 > 0) {
    String rest = line.substring(sp1 + 1); rest.trim();
    int sp2 = rest.indexOf(' ');
    a1 = sp2 > 0 ? rest.substring(0, sp2) : rest;
    a2 = sp2 > 0 ? rest.substring(sp2 + 1) : "";
    a2.trim();
  }
  auto hex = [](const String& s) { return (uint32_t)strtoul(s.c_str(), nullptr, 16); };

  switch (c) {
    case '?': help(); break;
    case 'E':
      digitalWrite(PIN_BUS_EN_N, a1.toInt() ? HIGH : LOW);
      Serial.printf("BUS_EN_N = %d (%s)\n", a1.toInt(), a1.toInt() ? "Hi-Z" : "enabled");
      break;
    case 'A':
      setAddr(hex(a1), hex(a2));
      Serial.printf("CPU A=$%04X  PPU A=$%04X\n", hex(a1) & 0x7FFF, hex(a2) & 0x3FFF);
      break;
    case 'C': setCtrl(a1, a2.toInt() ? HIGH : LOW); break;
    case 'I': idleBus(); Serial.println("control lines idle"); break;
    case 'R': { uint16_t v = read165();
      Serial.printf("CPU D=%02X  PPU D=%02X\n", v >> 8, v & 0xFF); } break;
    case 'G':
      Serial.printf("CIRAM_A10=%d  CIRAM_CE_N=%d\n",
                    digitalRead(PIN_CIRAM_A10), digitalRead(PIN_CIRAM_CE_N));
      break;
    case 'S':
      clkDelayUs = a1.toInt() > 1 ? (uint32_t)a1.toInt() : 1;
      Serial.printf("shift clock half-period = %u us\n", (unsigned)clkDelayUs);
      break;
    case 'V': cmdVector(); break;
    case 'P': case 'H': {
      uint16_t base = hex(a1);
      int n = a2.length() ? a2.toInt() : 16;
      uint8_t buf[16];
      for (int i = 0; i < n; i += 16) {
        int m = min(16, n - i);
        for (int j = 0; j < m; j++)
          buf[j] = (c == 'P') ? readPrg(base + i + j) : readChr(base + i + j);
        dumpLine(base + i, buf, m);
      }
    } break;
    case 'M': cmdMirror(); break;
    case 'D': cmdDump(); break;
    default: Serial.println("unknown command. ? for help");
  }
}

// ---------------------------------------------------------------
void setup() {
  // 出力ピンは「非アクティブ値を先に書いてから OUTPUT」にしてグリッチを防ぐ
  digitalWrite(PIN_BUS_EN_N, HIGH);  pinMode(PIN_BUS_EN_N, OUTPUT);
  digitalWrite(PIN_OE_DATA_N, HIGH); pinMode(PIN_OE_DATA_N, OUTPUT);
  digitalWrite(PIN_PL_165_N, HIGH);  pinMode(PIN_PL_165_N, OUTPUT);
  digitalWrite(PIN_RCLK_ADDR, LOW);  pinMode(PIN_RCLK_ADDR, OUTPUT);
  digitalWrite(PIN_RCLK_DATA, LOW);  pinMode(PIN_RCLK_DATA, OUTPUT);
  for (int p : {PIN_M2, PIN_ROMSEL_N, PIN_RW, PIN_PPU_RD_N, PIN_PPU_WR_N, PIN_PPU_A13_N})
    pinMode(p, OUTPUT);
  idleBus();
  pinMode(PIN_CIRAM_A10, INPUT);
  pinMode(PIN_CIRAM_CE_N, INPUT);

  digitalWrite(PIN_SCK, LOW);        pinMode(PIN_SCK, OUTPUT);
  digitalWrite(PIN_MOSI, LOW);       pinMode(PIN_MOSI, OUTPUT);
  pinMode(PIN_MISO, INPUT);
  setAddr(0, 0);

  Serial.begin(115200);
  delay(300);
  Serial.println("\nFamicom Dumper v3 (bit-bang + dump). BUS_EN_N=1 (Hi-Z) at boot");
  help();
}

void loop() {
  static String buf;
  while (Serial.available()) {
    char ch = Serial.read();
    if (ch == '\r' || ch == '\n') { handle(buf); buf = ""; }
    else buf += ch;
  }
}

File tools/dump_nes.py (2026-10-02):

#!/usr/bin/env python3
"""Famicom NROM dumper - PC side.

使い方:
    pip install pyserial
    python dump_nes.py COM5 smb.nes

前提: カセット挿入済み・SW1 ON。シリアルモニタは閉じておくこと（ポート占有）。
開始時に E 0（バス有効）、終了時に E 1（バスHi-Z）を自動で送る。
2回ダンプして一致した場合のみファイルを書き出す（接点不良による化けを検出）。
"""
import sys
import time
import zlib
import serial


def open_port(port: str) -> serial.Serial:
    s = serial.Serial()
    s.port = port
    s.baudrate = 115200
    s.timeout = 30
    s.dtr = False          # ESP32 DevKit の自動リセットを避ける
    s.rts = False
    s.open()
    time.sleep(2.0)        # 万一リセットされた場合の起動メッセージを待って捨てる
    s.reset_input_buffer()
    return s


def command(s: serial.Serial, cmd: str, expect: str) -> str:
    s.write((cmd + "\n").encode())
    for _ in range(20):
        line = s.readline().decode(errors="replace").strip()
        if line.startswith(expect):
            return line
    raise RuntimeError(f"no response to {cmd!r}")


def dump_once(s: serial.Serial):
    s.reset_input_buffer()
    s.write(b"D\n")
    header = s.readline().decode(errors="replace").strip()
    if not header.startswith("DUMP"):
        raise RuntimeError(f"unexpected header: {header!r}")
    info = dict(kv.split("=") for kv in header.split()[1:])
    prg_size, chr_size, mir = int(info["prg"]), int(info["chr"]), info["mir"]

    body = s.read(prg_size + chr_size)
    if len(body) != prg_size + chr_size:
        raise RuntimeError(f"short read: {len(body)} bytes")

    s.readline()                                  # 本体直後の改行
    tail = s.readline().decode(errors="replace").strip()
    crc_dev = int(tail.split("=")[1], 16)
    crc_pc = zlib.crc32(body) & 0xFFFFFFFF
    if crc_dev != crc_pc:
        raise RuntimeError(f"CRC mismatch: device {crc_dev:08X} / pc {crc_pc:08X}")

    return body[:prg_size], body[prg_size:], mir, crc_pc


def ines_header(prg_size: int, chr_size: int, mir: str) -> bytes:
    flags6 = 0x01 if mir == "V" else 0x00        # bit0: 1 = 垂直ミラー, Mapper 0
    return bytes([0x4E, 0x45, 0x53, 0x1A,
                  prg_size // 0x4000, chr_size // 0x2000,
                  flags6, 0x00]) + bytes(8)


def main():
    if len(sys.argv) != 3:
        print(__doc__)
        sys.exit(1)
    port, out = sys.argv[1], sys.argv[2]

    s = open_port(port)
    try:
        print(command(s, "E 0", "BUS_EN_N"))     # バス有効化

        t0 = time.time()
        prg1, chr1, mir1, crc1 = dump_once(s)
        print(f"pass 1: PRG {len(prg1)//1024}KB  CHR {len(chr1)//1024}KB  "
              f"mirror={mir1}  CRC32={crc1:08X}  ({time.time()-t0:.1f}s)")
        prg2, chr2, mir2, crc2 = dump_once(s)
        print(f"pass 2: CRC32={crc2:08X}")
    finally:
        # エラーで止まった場合も必ずバスをHi-Zに戻す（そのまま抜き差しできる状態にする）
        try:
            time.sleep(0.5)
            s.reset_input_buffer()
            print(command(s, "E 1", "BUS_EN_N"))
        except Exception:
            print("警告: E 1 を送れませんでした。カセットを抜く前にESP32のENボタンを押してください。")
        s.close()

    if (prg1, chr1, mir1) != (prg2, chr2, mir2):
        print("NG: 2回のダンプが一致しません。接点清掃・挿し直し後に再実行してください。")
        sys.exit(2)
    if mir1 == "?":
        print("注意: ミラーリング判定不能。水平(H)として書き出します。")

    rom = ines_header(len(prg1), len(chr1), mir1) + prg1 + chr1
    with open(out, "wb") as f:
        f.write(rom)
    print(f"OK: {out} ({len(rom)} bytes)  PRG+CHR CRC32={crc1:08X}")


if __name__ == "__main__":
    main()
